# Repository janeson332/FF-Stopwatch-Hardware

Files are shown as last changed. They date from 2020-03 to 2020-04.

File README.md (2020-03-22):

# FF-Stopwatch-Hardware
This Repo contains the hardware layout of the FF-Stopwatch project. The project
has been designed in EAGLE

## Folderstructure
| ..  
|-- doc      &nbsp;&nbsp;&nbsp;&nbsp;&nbsp;&nbsp;&nbsp;&nbsp;&nbsp; < contains docoumentation  
|-- Lib      &nbsp;&nbsp;&nbsp;&nbsp;&nbsp;&nbsp;&nbsp;&nbsp;&nbsp;&nbsp; < Eagle library files  
|-- schematic   < schematic and layout (eagle)  
|-- images   &nbsp;&nbsp;&nbsp;&nbsp; < images of the layout

### bare board
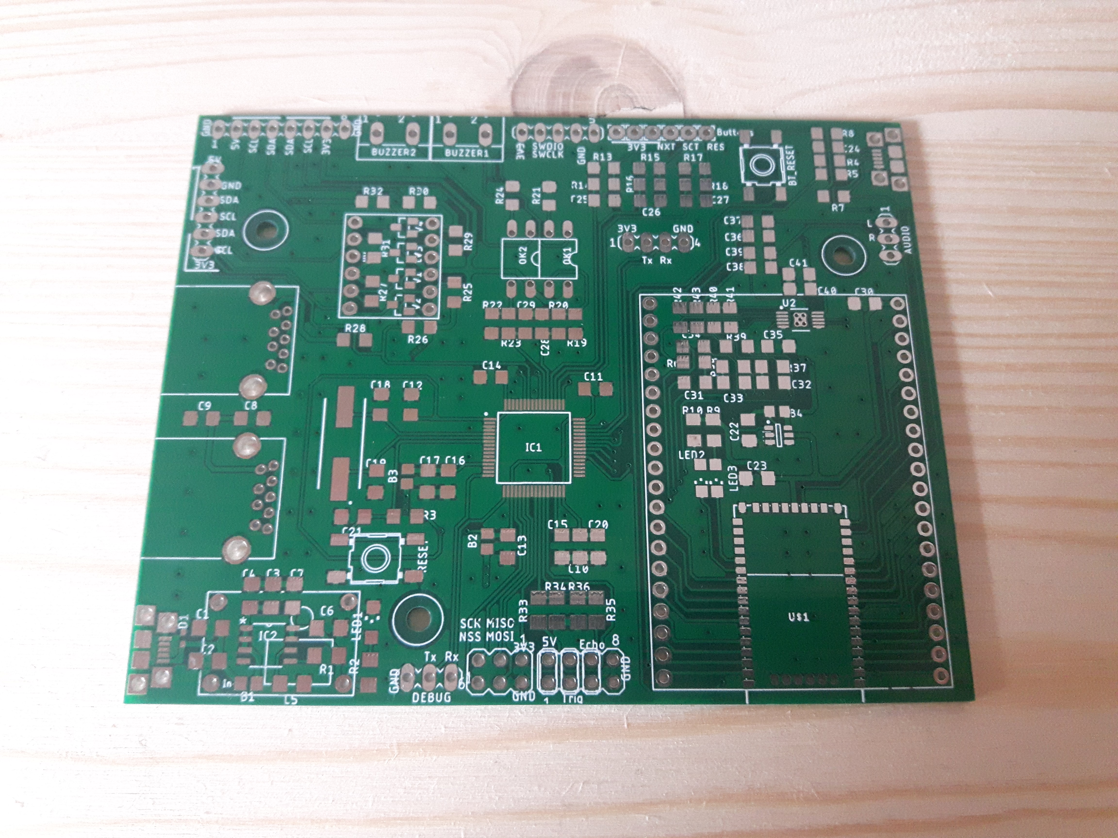
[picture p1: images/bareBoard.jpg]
bare board


### assembled board
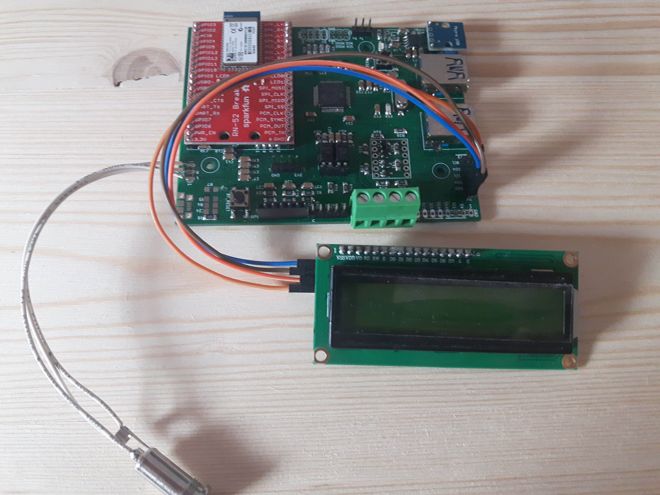
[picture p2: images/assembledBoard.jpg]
bare board


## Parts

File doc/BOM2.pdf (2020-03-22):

Part | Value | Device | Package | Description
AUDIO | | MA03-1 | MA03-1 | PIN HEADER
B1 | B-EU_B0805 L0805 | EMI Filter
B2 | B-EU_B0805 L0805 | EMI Filter
B3 | B-EU_B0805 L0805 | EMI Filter
B4 | B-EU_B0805 L0805 | EMI Filter
BTN_NXT/1 WIREPAD2,15/1,0 WIREPAD2,15/1,0 2,15/1,0 | Wire PAD connect wire on PCB
BTN_RES/1 | WIREPAD2,15/1,0 WIREPAD2,15/1,0 2,15/1,0 | Wire PAD connect wire on PCB
BTN_SCT/1 | WIREPAD2,15/1,0 WIREPAD2,15/1,0 2,15/1,0 | Wire PAD connect wire on PCB
BT_RESET | FactoryReset TASTER_SMD TASTER_SMD_LSG-LSH1301XX 6.0 X 6.0mm TACT Switch (SMD) - Schurter Typ LSG/LSH 1301.xx
BUZZER1 | | W237-102 | W237-102 | WAGO SCREW CLAMP
BUZZER2 | | W237-102 | W237-102 | WAGO SCREW CLAMP
C1 | 10u | C-EUC1206 | C1206 | CAPACITOR, European symbol
C2 | 100n | C-EUC1206 | C1206 | CAPACITOR, European symbol
C3 | 100n | C-EUC1206 | C1206 | CAPACITOR, European symbol
C4 | 10u | C-EUC1206 | C1206 | CAPACITOR, European symbol
C5 | 100n | C-EUC1206 | C1206 | CAPACITOR, European symbol
C6 | 100n | C-EUC1206 | C1206 | CAPACITOR, European symbol
C7 | 10u | C-EUC1206 | C1206 | CAPACITOR, European symbol
C8 | 100n | C-EUC1206 | C1206 | CAPACITOR, European symbol
C9 | 100n | C-EUC1206 | C1206 | CAPACITOR, European symbol
C10 | 10u | C-EUC1206 | C1206 | CAPACITOR, European symbol
C11 | 100n | C-EUC1206 | C1206 | CAPACITOR, European symbol
C12 | 100n | C-EUC1206 | C1206 | CAPACITOR, European symbol
C13 | 100n | C-EUC1206 | C1206 | CAPACITOR, European symbol
C14 | 100n | C-EUC1206 | C1206 | CAPACITOR, European symbol
C15 | 4u7 | C-EUC1206 | C1206 | CAPACITOR, European symbol
C16 | 1u | C-EUC1206 | C1206 | CAPACITOR, European symbol
C17 | 100n | C-EUC1206 | C1206 | CAPACITOR, European symbol
C18 | 15p | C-EUC1206 | C1206 | CAPACITOR, European symbol
C19 | 15p | C-EUC1206 | C1206 | CAPACITOR, European symbol
C20 | 100n | C-EUC1206 | C1206 | CAPACITOR, European symbol
C21 | 100n | C-EUC1206 | C1206 | CAPACITOR, European symbol

C22 | 100n | C-EUC1206 | C1206 | CAPACITOR, European symbol
C23 | 100n | C-EUC1206 | C1206 | CAPACITOR, European symbol
C24 | 100n | C-EUC1206 | C1206 | CAPACITOR, European symbol
C25 | 100n | C-EUC1206 | C1206 | CAPACITOR, European symbol
C26 | 100n | C-EUC1206 | C1206 | CAPACITOR, European symbol
C27 | 100n | C-EUC1206 | C1206 | CAPACITOR, European symbol
C28 | 100n | C-EUC1206 | C1206 | CAPACITOR, European symbol
C29 | 100n | C-EUC1206 | C1206 | CAPACITOR, European symbol
C30 | 100n | C-EUC1206 | C1206 | CAPACITOR, European symbol
C31 | 1u | C-EUC1206 | C1206 | CAPACITOR, European symbol
C32 | 1u | C-EUC1206 | C1206 | CAPACITOR, European symbol
C33 | 1u | C-EUC1206 | C1206 | CAPACITOR, European symbol
C34 | 1u | C-EUC1206 | C1206 | CAPACITOR, European symbol
C35 | 1u | C-EUC1206 | C1206 | CAPACITOR, European symbol
C36 | 100n | C-EUC1206 | C1206 | CAPACITOR, European symbol
C37 | 100n | C-EUC1206 | C1206 | CAPACITOR, European symbol
C38 | 100n | C-EUC1206 | C1206 | CAPACITOR, European symbol
C39 | 100n | C-EUC1206 | C1206 | CAPACITOR, European symbol
C40 | 10u | C-EUC1206 | C1206 | CAPACITOR, European symbol
C41 | 100n | C-EUC1206 | C1206 | CAPACITOR, European symbol
D1 | PESD5V0S1UBDIODE-SOD523SOD523 | DIODE
DEBUG | | MA03-1 | MA03-1 | PIN HEADER
H1 | MOUNT-HOLE2.8 MOUNT-HOLE2.8 | 2,8 MOUNTING HOLE with drill center marker
H2 | MOUNT-HOLE2.8 MOUNT-HOLE2.8 | 2,8 MOUNTING HOLE with drill center marker
H3 | MOUNT-HOLE2.8 MOUNT-HOLE2.8 | 2,8 MOUNTING HOLE with drill center marker
IC1 | STM32F401RET6STM32F401RET6QFP50P1200X1200X160-64N ARM Cortex-M4 32b MCU+FPU
IC2 | MCP1725-3302E/SN MCP1725-3302E/SN SOIC127P600X175-8N Low Quiescent Current LDO Regulator
J1 | USB-A3-0 | USB3_TYPE_A WR-COM USB 3.0 HORIZONTAL TYPE A=>Code : Con_I-O_COM_USB-3.0_A_629121030100
J2 | USB-A3-0 | USB3_TYPE_A WR-COM USB 3.0 HORIZONTAL TYPE A=>Code : Con_I-O_COM_USB-3.0_A_629121030100
LED1 | RED | LEDCHIPLED_1206 CHIPLED_1206LED
LED2 | GREEN | LEDCHIPLED_1206 CHIPLED_1206LED
LED3 | RED | LEDCHIPLED_1206 CHIPLED_1206LED
NXT | WIREPAD2,15/1,0 WIREPAD2,15/1,0 2,15/1,0 | Wire PAD connect wire on PCB

OK1 | PC817 | PC817 | DIL04 | SHARP OPTO COUPLER
OK2 | PC817 | PC817 | DIL04 | SHARP OPTO COUPLER
Q1 | 8MHz | FOXSDLF_080-20FOXSDLF/080-20Crystal SMD 8.000MHz HC49S-SMD Crystal 8MHz, 30ppm, 2-Pin SMD, 11.7 x 5 x 4.5mm
R1 | 100k | R-EU_R1206 R1206 | RESISTOR, European symbol
R2 | 330R | R-EU_R1206 R1206 | RESISTOR, European symbol
R3 | 100k | R-EU_R1206 R1206 | RESISTOR, European symbol
R4 | 22k | R-EU_R1206 R1206 | RESISTOR, European symbol
R5 | 47k | R-EU_R1206 R1206 | RESISTOR, European symbol
R6 | 22k | R-EU_R1206 R1206 | RESISTOR, European symbol
R7 | 1k5 | R-EU_R1206 R1206 | RESISTOR, European symbol
R8 | 1k5 | R-EU_R1206 R1206 | RESISTOR, European symbol
R9 | 330 R-EU_R1206 R1206 | RESISTOR, European symbol
R10 | 330 R-EU_R1206 R1206 | RESISTOR, European symbol
R13 | 10k | R-EU_R1206 R1206 | RESISTOR, European symbol
R14 | 10k | R-EU_R1206 R1206 | RESISTOR, European symbol
R15 | 10k | R-EU_R1206 R1206 | RESISTOR, European symbol
R16 | 10k | R-EU_R1206 R1206 | RESISTOR, European symbol
R17 | 10k | R-EU_R1206 R1206 | RESISTOR, European symbol
R18 | 10k | R-EU_R1206 R1206 | RESISTOR, European symbol
R19 | 10k | R-EU_R1206 R1206 | RESISTOR, European symbol
R20 | 10k | R-EU_R1206 R1206 | RESISTOR, European symbol
R21 | 330R | R-EU_R1206 R1206 | RESISTOR, European symbol
R22 | 10k | R-EU_R1206 R1206 | RESISTOR, European symbol
R23 | 10k | R-EU_R1206 R1206 | RESISTOR, European symbol
R24 | 330R | R-EU_R1206 R1206 | RESISTOR, European symbol
R25 | 3k3 | R-EU_R1206 R1206 | RESISTOR, European symbol
R26 | 3k3 | R-EU_R1206 R1206 | RESISTOR, European symbol
R27 | 4k7 | R-EU_R1206 R1206 | RESISTOR, European symbol
R28 | 4k7 | R-EU_R1206 R1206 | RESISTOR, European symbol
R29 | 3k3 | R-EU_R1206 R1206 | RESISTOR, European symbol
R30 | 3k3 | R-EU_R1206 R1206 | RESISTOR, European symbol
R31 | 4k7 | R-EU_R1206 R1206 | RESISTOR, European symbol
R32 | 4k7 | R-EU_R1206 R1206 | RESISTOR, European symbol

R33 | 22k | R-EU_R1206 R1206 | RESISTOR, European symbol
R34 | 47k | R-EU_R1206 R1206 | RESISTOR, European symbol
R35 | 22k | R-EU_R1206 R1206 | RESISTOR, European symbol
R36 | 47k | R-EU_R1206 R1206 | RESISTOR, European symbol
R37 | 22k | R-EU_R1206 R1206 | RESISTOR, European symbol
R38 | 22k | R-EU_R1206 R1206 | RESISTOR, European symbol
R39 | 22k | R-EU_R1206 R1206 | RESISTOR, European symbol
R40 | 47k | R-EU_R1206 R1206 | RESISTOR, European symbol
R41 | 47k | R-EU_R1206 R1206 | RESISTOR, European symbol
R42 | 47k | R-EU_R1206 R1206 | RESISTOR, European symbol
R43 | 47k | R-EU_R1206 R1206 | RESISTOR, European symbol
RES | WIREPAD2,15/1,0 WIREPAD2,15/1,0 2,15/1,0 | Wire PAD connect wire on PCB
RESET | Reset | TASTER_SMD TASTER_SMD_LSG-LSH1301XX 6.0 X 6.0mm TACT Switch (SMD) - Schurter Typ LSG/LSH 1301.xx
SCT | WIREPAD2,15/1,0 WIREPAD2,15/1,0 2,15/1,0 | Wire PAD connect wire on PCB
SV1 | | MA05-1 | MA05-1 | PIN HEADER
SV2 | | MA04-2 | MA04-2 | PIN HEADER
SV3 | | MA06-1 | MA06-1 | PIN HEADER
SV5 | | MA04-1 | MA04-1 | PIN HEADER
SV6 | | MA03-2 | MA03-2 | PIN HEADER
SV7 | | MA08-1 | MA08-1 | PIN HEADER
U$1 | BLUETOOTH-RN-52 BLUETOOTH-RN-52 RN-52 | Roving Networks RN-52 Bluetooth Audio Module
U$2 | SPARKFUN-RN52SPARKFUN-RN52SPARKFUN-RN52
U$3 | I2C-LEVELCONVERTER-PCB I2C-LEVELCONVERTER-PCB I2C-LEVELCONVERTER-PCB
U$4 | RC-STEP-DOWNRC-STEP-DOWNRC-STEP-DOWN
U1 | ANALOG_DEVICES_ADG819BRTZ-500RL7ANALOG_DEVICES_ADG819BRTZ-500RL7_0_1 ANALOG_DEVICES_ADG819BRTZ-500RL7ANALOG_DEVICES_ADG819BRTZ-500RL7_0_1 ANALOG_DEVICES_ADG819BRTZ-500RL7_1 ADI-ADG819-RJ-6
U2 | TEXAS_INSTRUMENTS_TPA6112A2DGQRTEXAS_INSTRUMENTS_TPA6112A2DGQR_0_1 TEXAS_INSTRUMENTS_TPA6112A2DGQRTEXAS_INSTRUMENTS_TPA6112A2DGQR_0_1 TEXAS_INSTRUMENTS_TPA6112A2DGQR_1 TI-TPA6112A2DGQ10-1675X1445TP
USB1 | MICRO-USB MICRO-USB ZX62B5PA
USB2 | MICRO-USB MICRO-USB ZX62B5PA
V1 | FDN337N | FDN337N | SOT23 | N-CHANNEL MOS FET
V2 | FDN337N | FDN337N | SOT23 | N-CHANNEL MOS FET
V3 | FDN337N | FDN337N | SOT23 | N-CHANNEL MOS FET
V4 | FDN337N | FDN337N | SOT23 | N-CHANNEL MOS FET

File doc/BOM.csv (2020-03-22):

Qty | Value | Device | Package | Parts | Description
4 |  | B-EU_B0805 | L0805 | B1, B2, B3, B4 | EMI Filter
2 |  | MA03-1 | MA03-1 | AUDIO, DEBUG | PIN HEADER
1 |  | MA03-2 | MA03-2 | SV6 | PIN HEADER
1 |  | MA04-1 | MA04-1 | SV5 | PIN HEADER
1 |  | MA04-2 | MA04-2 | SV2 | PIN HEADER
1 |  | MA05-1 | MA05-1 | SV1 | PIN HEADER
1 |  | MA06-1 | MA06-1 | SV3 | PIN HEADER
1 |  | MA08-1 | MA08-1 | SV7 | PIN HEADER
2 |  | USB-A3-0 | USB3_TYPE_A | J1, J2 | WR-COM USB 3.0 HORIZONTAL TYPE A=>Code : Con_I-O_COM_USB-3.0_A_629121030100
2 |  | W237-102 | W237-102 | BUZZER1, BUZZER2 | WAGO SCREW CLAMP
2 | 100k | R-EU_R1206 | R1206 | R1, R3 | RESISTOR, European symbol
27 | 100n | C-EUC1206 | C1206 | C2, C3, C5, C6, C8, C9, C11, C12, C13, C14, C17, C20, C21, C22, C23, C24, C25, C26, C27, C28, C29, C30, C36, C37, C38, C39, C41 | CAPACITOR, European symbol
10 | 10k | R-EU_R1206 | R1206 | R13, R14, R15, R16, R17, R18, R19, R20, R22, R23 | RESISTOR, European symbol
5 | 10u | C-EUC1206 | C1206 | C1, C4, C7, C10, C40 | CAPACITOR, European symbol
2 | 15p | C-EUC1206 | C1206 | C18, C19 | CAPACITOR, European symbol
2 | 1k5 | R-EU_R1206 | R1206 | R7, R8 | RESISTOR, European symbol
6 | 1u | C-EUC1206 | C1206 | C16, C31, C32, C33, C34, C35 | CAPACITOR, European symbol
7 | 22k | R-EU_R1206 | R1206 | R4, R6, R33, R35, R37, R38, R39 | RESISTOR, European symbol
2 | 330 | R-EU_R1206 | R1206 | R9, R10 | RESISTOR, European symbol
3 | 330R | R-EU_R1206 | R1206 | R2, R21, R24 | RESISTOR, European symbol
4 | 3k3 | R-EU_R1206 | R1206 | R25, R26, R29, R30 | RESISTOR, European symbol
7 | 47k | R-EU_R1206 | R1206 | R5, R34, R36, R40, R41, R42, R43 | RESISTOR, European symbol
4 | 4k7 | R-EU_R1206 | R1206 | R27, R28, R31, R32 | RESISTOR, European symbol
1 | 4u7 | C-EUC1206 | C1206 | C15 | CAPACITOR, European symbol
1 | 8MHz | FOXSDLF_080-20 | FOXSDLF/080-20 | Q1 | Crystal SMD 8.000MHz HC49S-SMD Crystal 8MHz, 30ppm, 2-Pin SMD, 11.7 x 5 x 4.5mm
1 | ANALOG_DEVICES_ADG819BRTZ-500RL7ANALOG_DEVICES_ADG819BRTZ-500RL7_0_1 | ANALOG_DEVICES_ADG819BRTZ-500RL7ANALOG_DEVICES_ADG819BRTZ-500RL7_0_1 | ANALOG_DEVICES_ADG819BRTZ-500RL7_1 | U1 | ADI-ADG819-RJ-6
1 | BLUETOOTH-RN-52 | BLUETOOTH-RN-52 | RN-52 | U$1 | Roving Networks RN-52 Bluetooth Audio Module
4 | FDN337N | FDN337N | SOT23 | V1, V2, V3, V4 | N-CHANNEL MOS FET
1 | FactoryReset | TASTER_SMD | TASTER_SMD_LSG-LSH1301XX | BT_RESET | 6.0 X 6.0mm TACT Switch (SMD) - Schurter Typ LSG/LSH 1301.xx
1 | GREEN | LEDCHIPLED_1206 | CHIPLED_1206 | LED2 | LED
1 | I2C-LEVELCONVERTER-PCB | I2C-LEVELCONVERTER-PCB | I2C-LEVELCONVERTER-PCB | U$3
1 | MCP1725-3302E/SN | MCP1725-3302E/SN | SOIC127P600X175-8N | IC2 | Low Quiescent Current LDO Regulator
2 | MICRO-USB | MICRO-USB | ZX62B5PA | USB1, USB2
3 | MOUNT-HOLE2.8 | MOUNT-HOLE2.8 | 2,8 | H1, H2, H3 | MOUNTING HOLE with drill center marker
2 | PC817 | PC817 | DIL04 | OK1, OK2 | SHARP OPTO COUPLER
1 | PESD5V0S1UB | DIODE-SOD523 | SOD523 | D1 | DIODE
1 | RC-STEP-DOWN | RC-STEP-DOWN | RC-STEP-DOWN | U$4
2 | RED | LEDCHIPLED_1206 | CHIPLED_1206 | LED1, LED3 | LED
1 | Reset | TASTER_SMD | TASTER_SMD_LSG-LSH1301XX | RESET | 6.0 X 6.0mm TACT Switch (SMD) - Schurter Typ LSG/LSH 1301.xx
1 | SPARKFUN-RN52 | SPARKFUN-RN52 | SPARKFUN-RN52 | U$2
1 | STM32F401RET6 | STM32F401RET6 | QFP50P1200X1200X160-64N | IC1 | ARM Cortex-M4 32b MCU+FPU
1 | TEXAS_INSTRUMENTS_TPA6112A2DGQRTEXAS_INSTRUMENTS_TPA6112A2DGQR_0_1 | TEXAS_INSTRUMENTS_TPA6112A2DGQRTEXAS_INSTRUMENTS_TPA6112A2DGQR_0_1 | TEXAS_INSTRUMENTS_TPA6112A2DGQR_1 | U2 | TI-TPA6112A2DGQ10-1675X1445TP
6 | WIREPAD2,15/1,0 | WIREPAD2,15/1,0 | 2,15/1,0 | BTN_NXT/1, BTN_RES/1, BTN_SCT/1, NXT, RES, SCT | Wire PAD connect wire on PCB

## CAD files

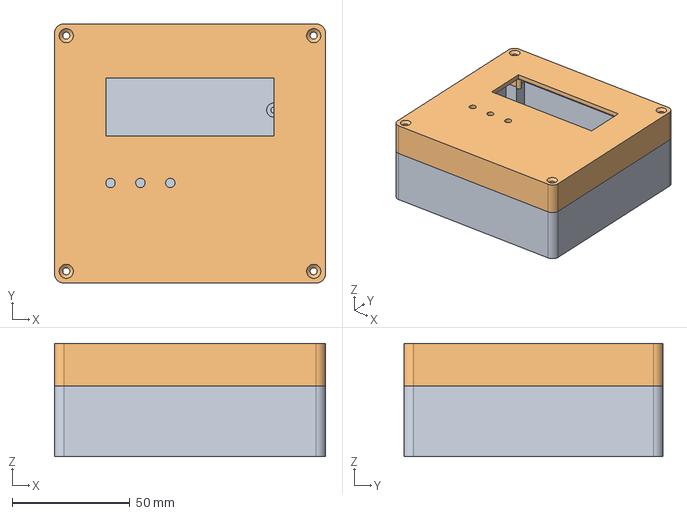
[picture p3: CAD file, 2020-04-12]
Case/Assembled.FCStd
115.0 x 110.0 x 48.0 mm
Case2_001
Cover_001

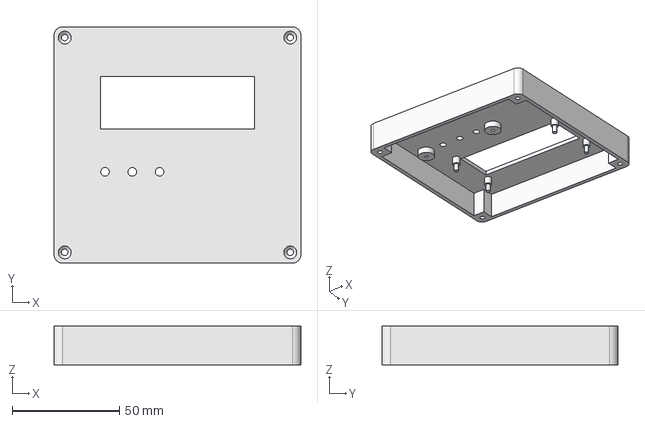
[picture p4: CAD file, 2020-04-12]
Case/Cover.FCStd
115.0 x 110.0 x 18.0 mm

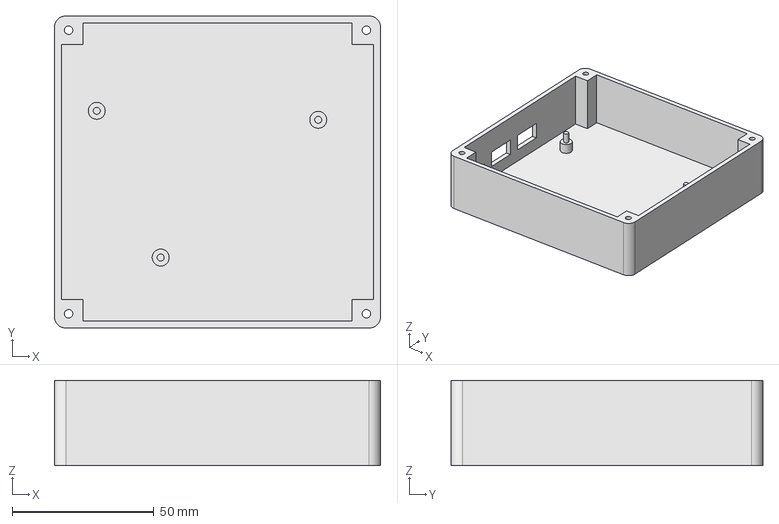
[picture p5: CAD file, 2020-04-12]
Case/Case2.FCStd
115.0 x 110.0 x 30.0 mm

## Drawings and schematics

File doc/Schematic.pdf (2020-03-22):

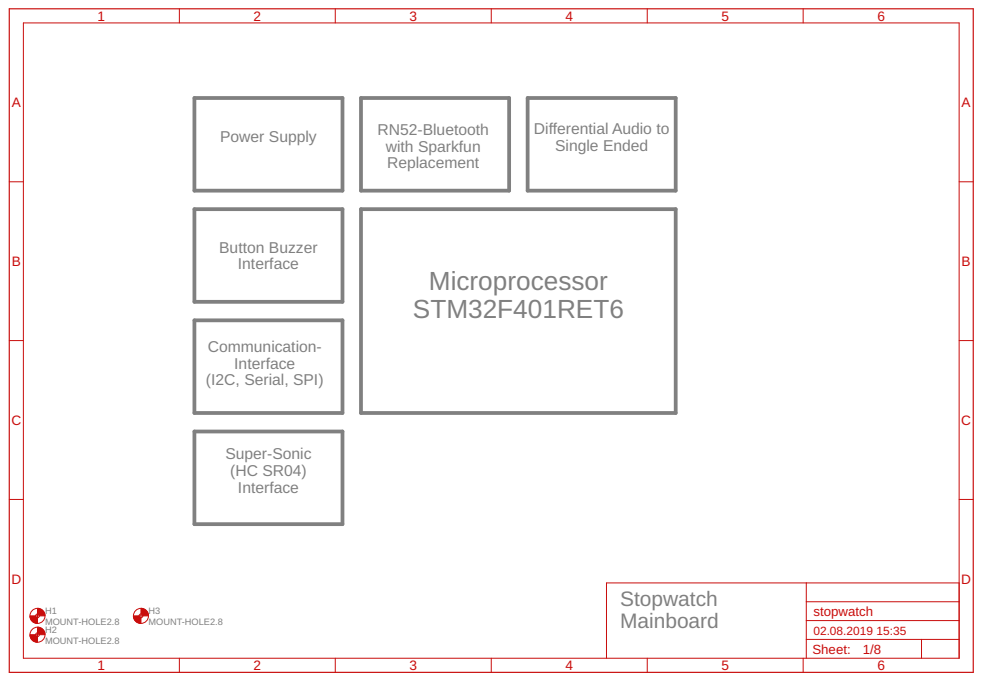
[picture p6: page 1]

Stopwatch

Sheet: 1/8

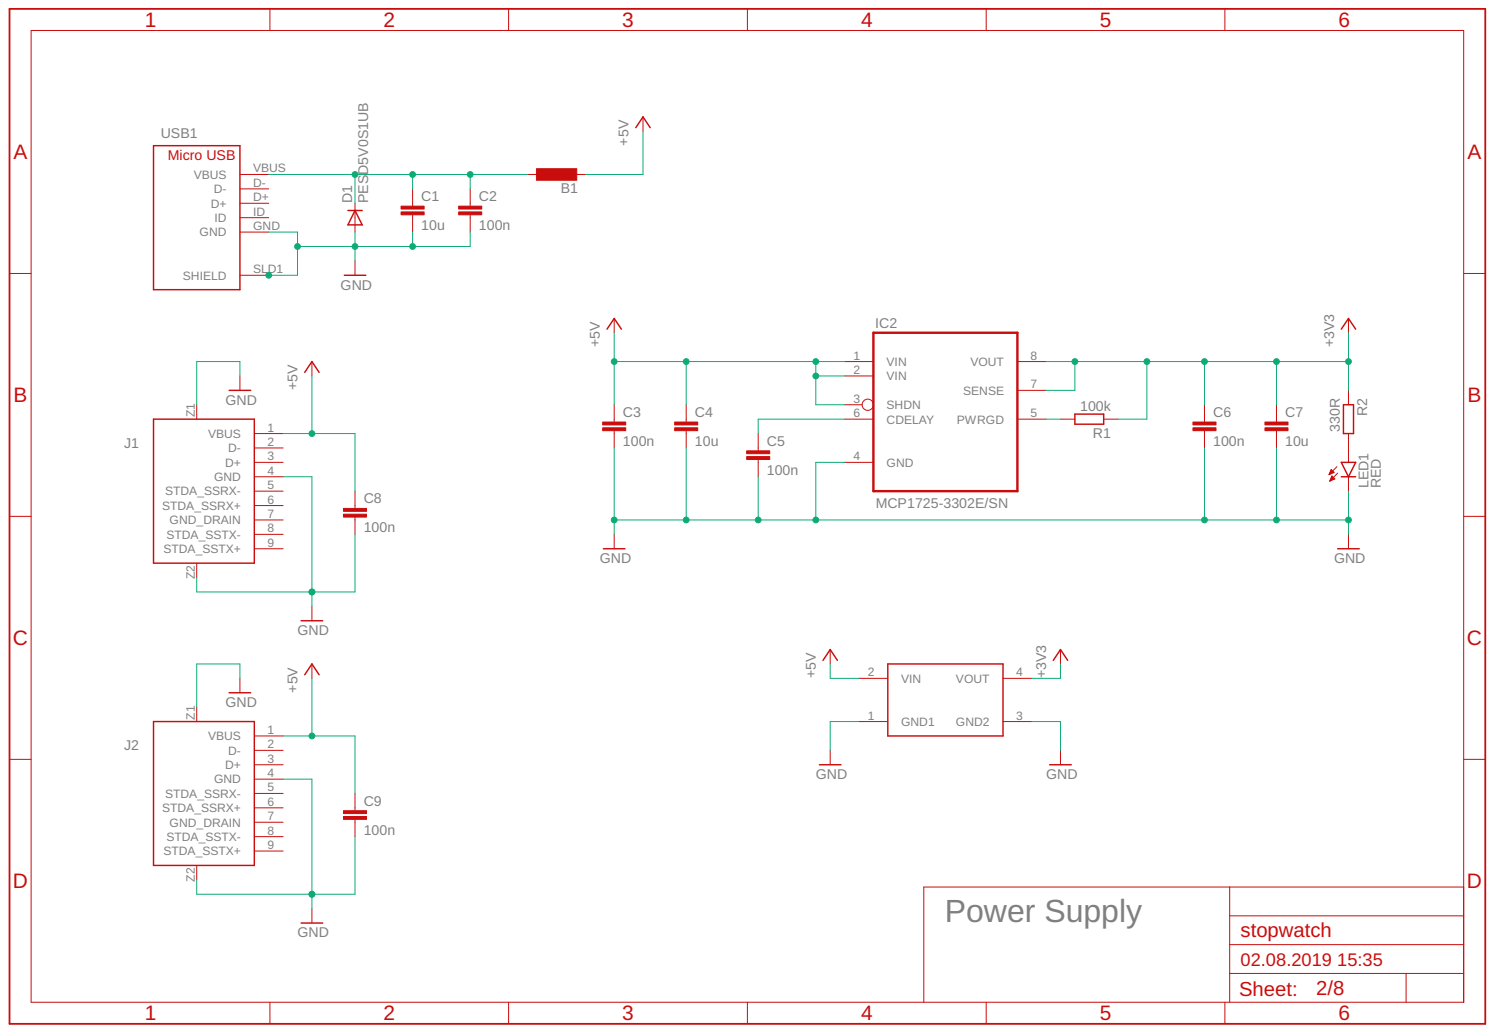
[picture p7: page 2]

PESD5V0S1UB 10u 100n GND +5V +5V GND100n 10u 100n 100k 100n 10u GND 330R RED +3V3 +5V GND GND 100n +5V GND GND 100n +5V +3V3 GND GND MCP1725-3302E/SN Power Supply VBUS VBUS D- D- D+ D+ ID ID GND GND SHIELD SLD1 USB1 D1C1 C2 B1 C3 C4 C5 R1 C6 C7 R2 LED1 J1 VBUS 1 D- 2 D+ 3 GND 4 STDA_SSRX- 5 STDA_SSRX+ 6 GND_DRAIN 7 STDA_SSTX- 8 STDA_SSTX+ 9 Z1 Z2 C8 J2 VBUS 1 D- 2 D+ 3 GND 4 STDA_SSRX- 5 STDA_SSRX+ 6 GND_DRAIN 7 STDA_SSTX- 8 STDA_SSTX+ 9 Z1 Z2 C9 VIN 2 GND1 1 VOUT 4 GND2 3 CDELAY 6 GND 4 PWRGD 5 SENSE 7 SHDN 3 VIN 1 VIN 2 VOUT 8 IC2 stopwatch 02.08.2019 15:35 Sheet: 2/8 ABCD 1 2 3 4 5 6 ABCD 1 2 3 4 5 6 Micro USB

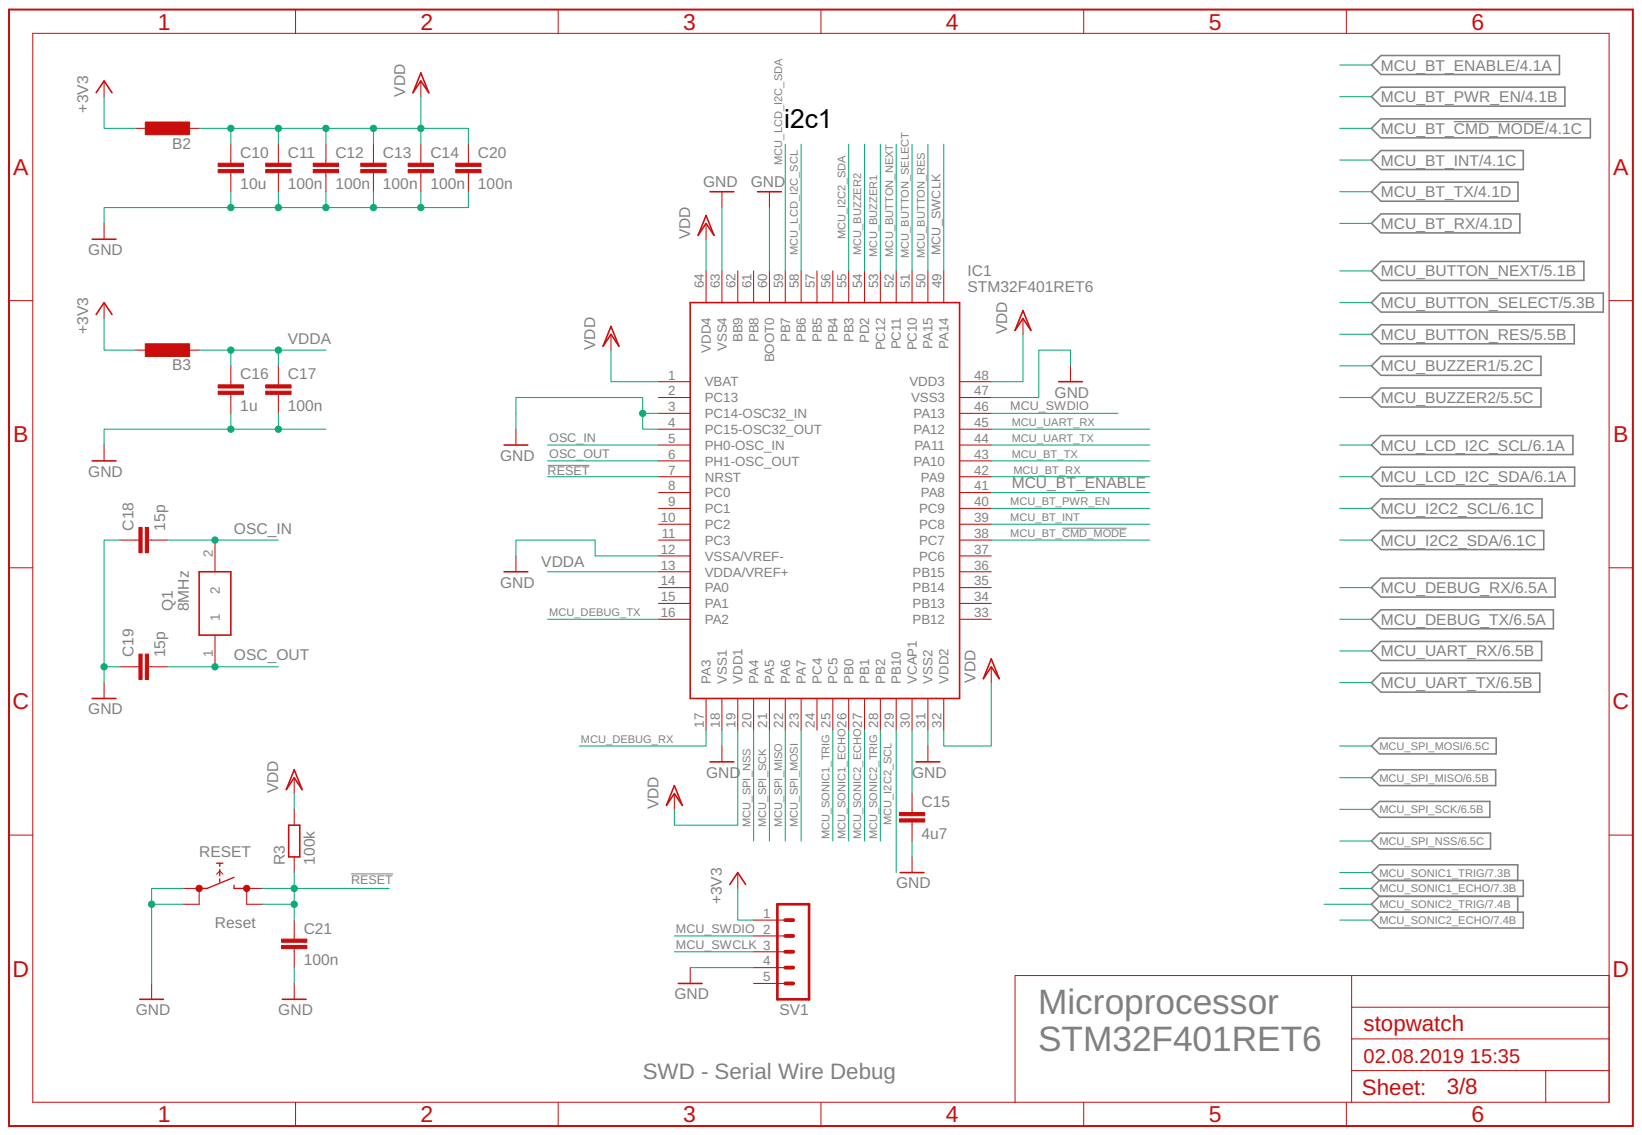
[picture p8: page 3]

Microprocessor STM32F401RET6

SWD - Serial Wire Debug

Sheet: 3/8

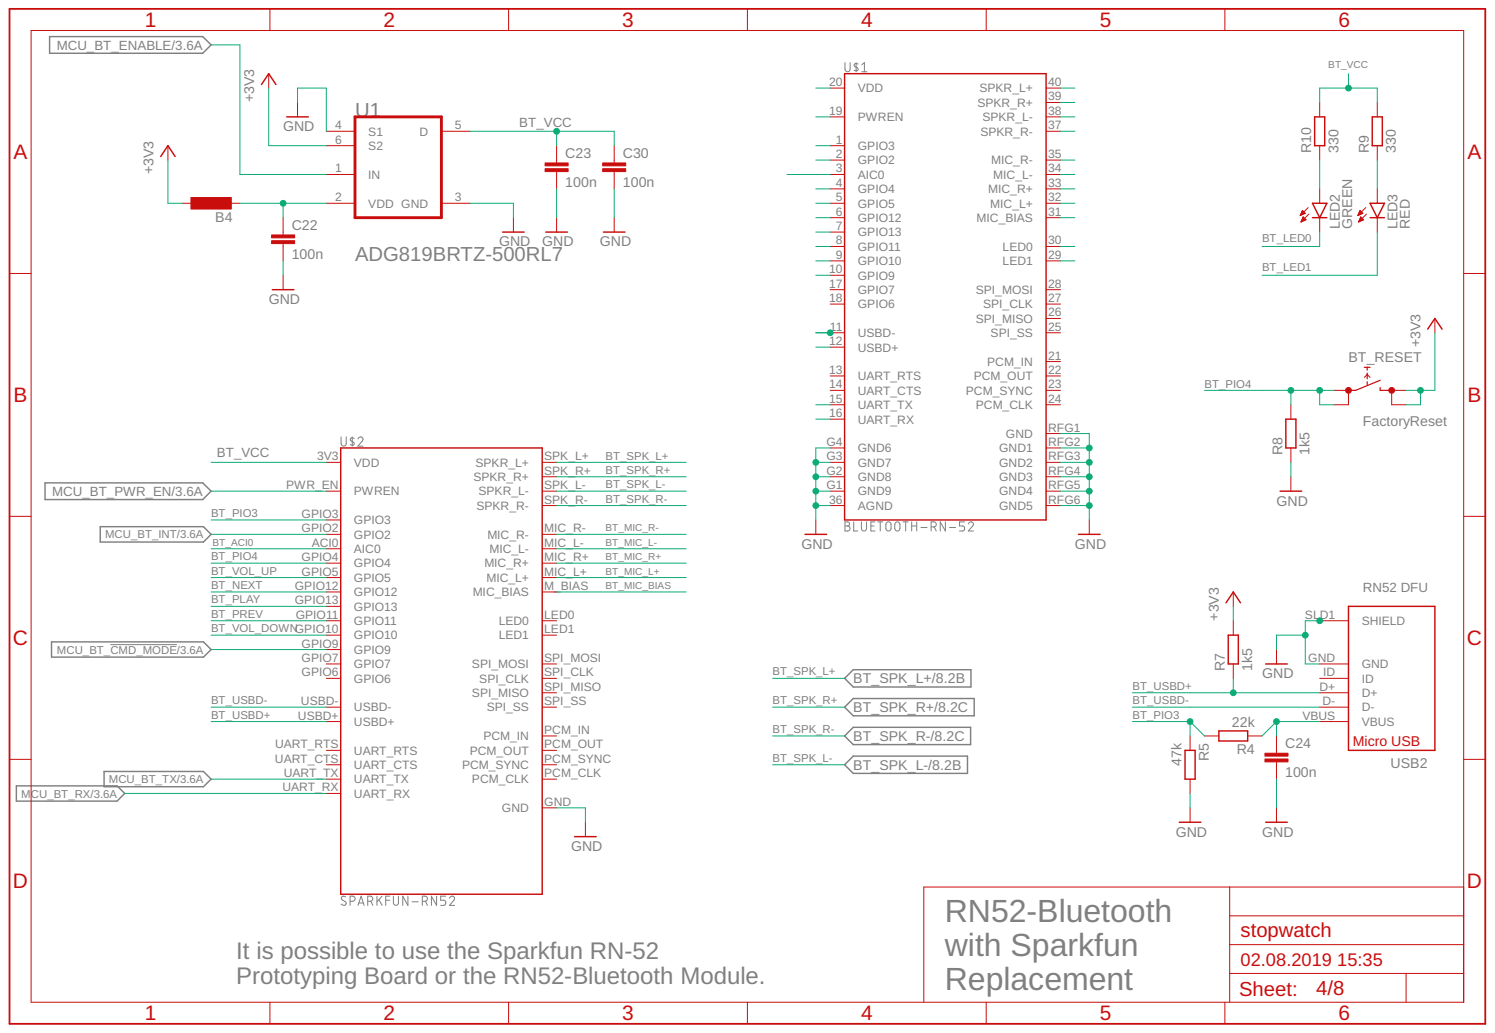
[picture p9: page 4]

RN52-Bluetooth with Sparkfun Replacement

It is possible to use the Sparkfun RN-52
Prototyping Board or the RN52-Bluetooth Module.

Sheet: 4/8

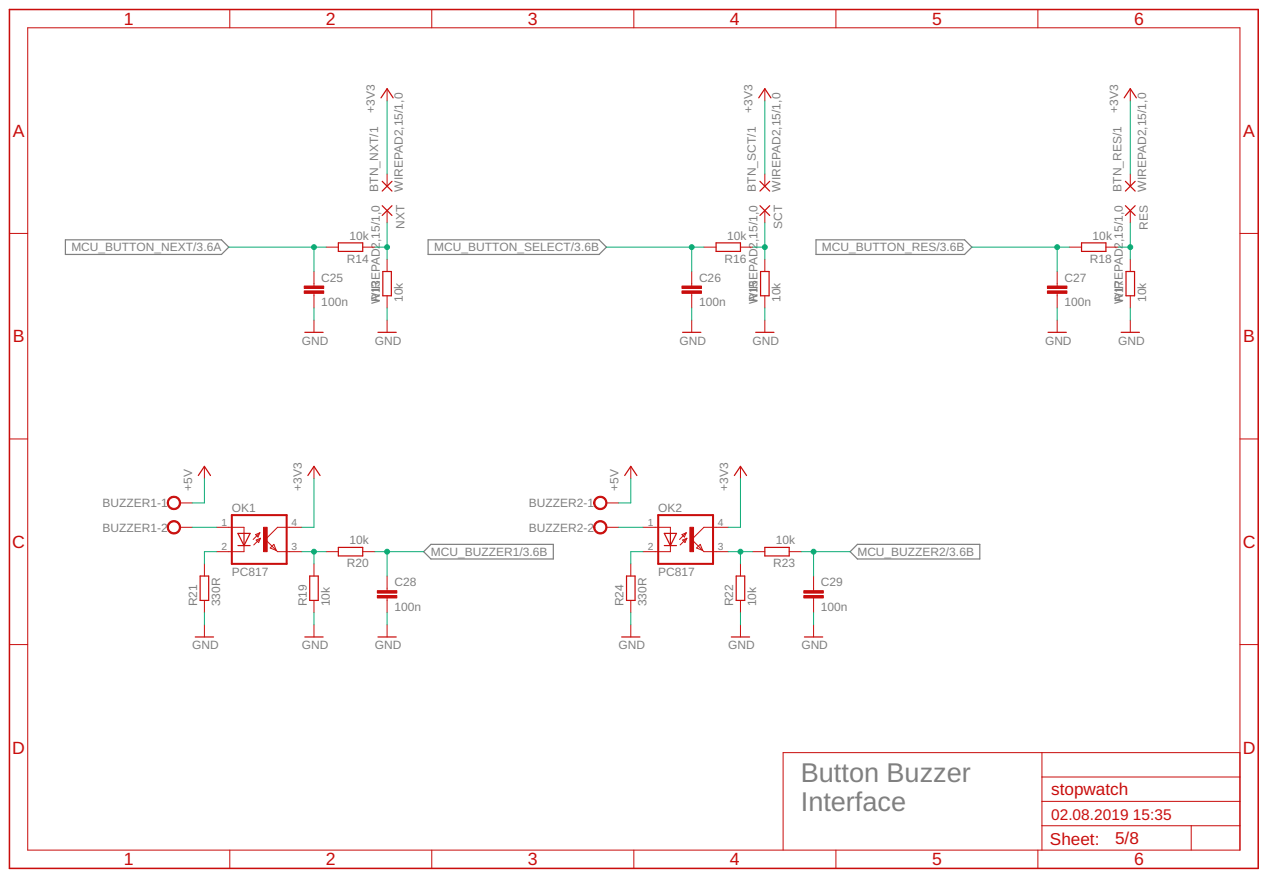
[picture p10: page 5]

Button Buzzer Interface

Sheet: 5/8

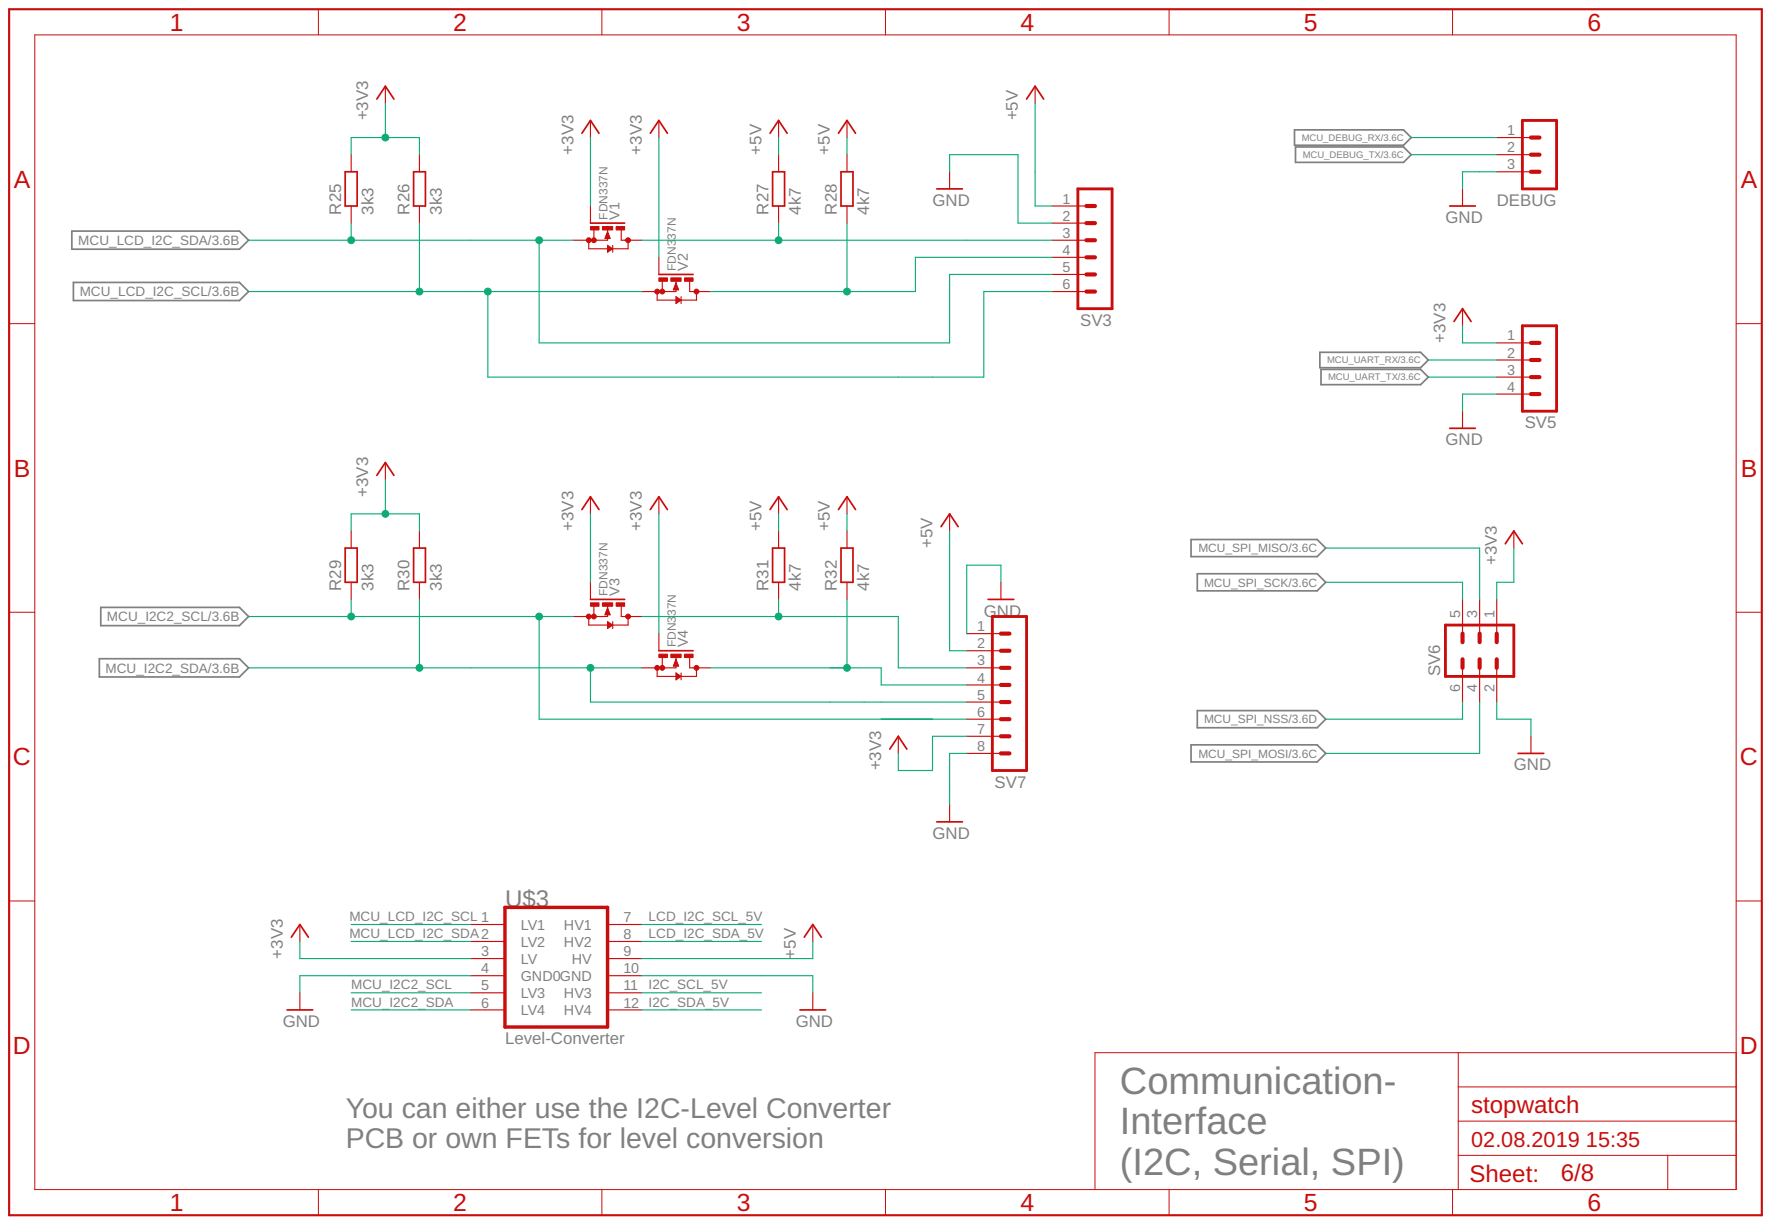
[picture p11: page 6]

Communication-Interface (I2C, Serial, SPI)

You can either use the I2C-Level Converter
PCB or own FETs for level conversion

Sheet: 6/8

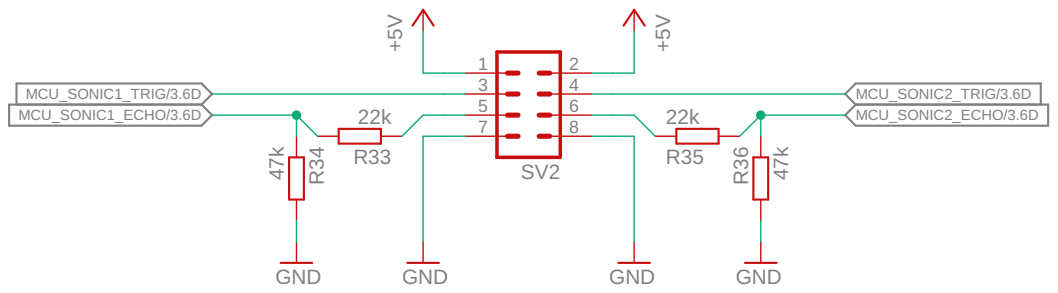
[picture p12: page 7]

Super-Sonic (HC SR04) Interface

Sheet: 7/8

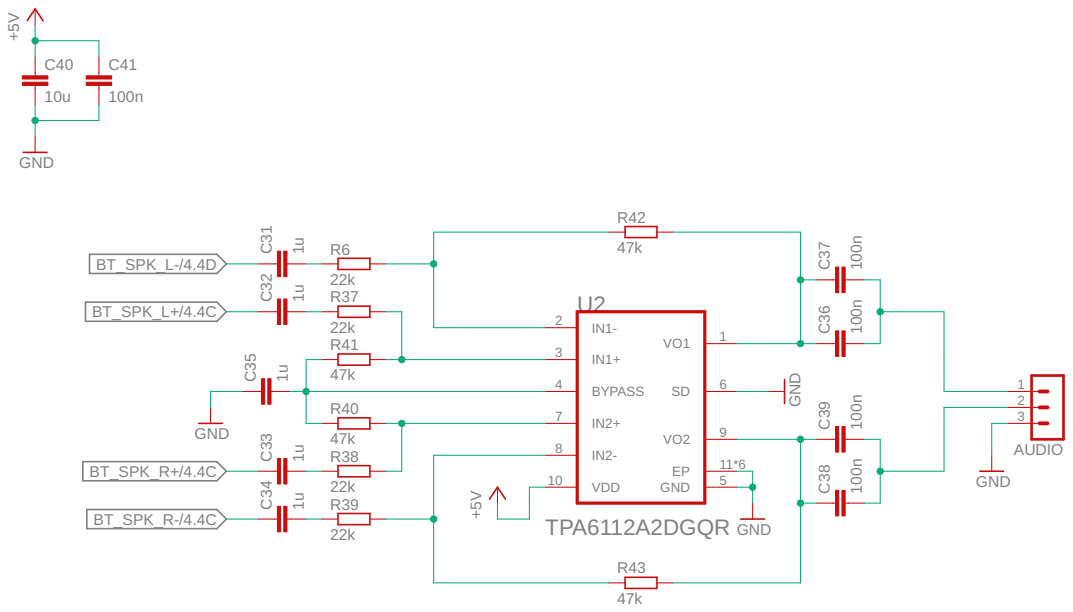
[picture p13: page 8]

Differential Audio to Single Ended

Sheet: 8/8

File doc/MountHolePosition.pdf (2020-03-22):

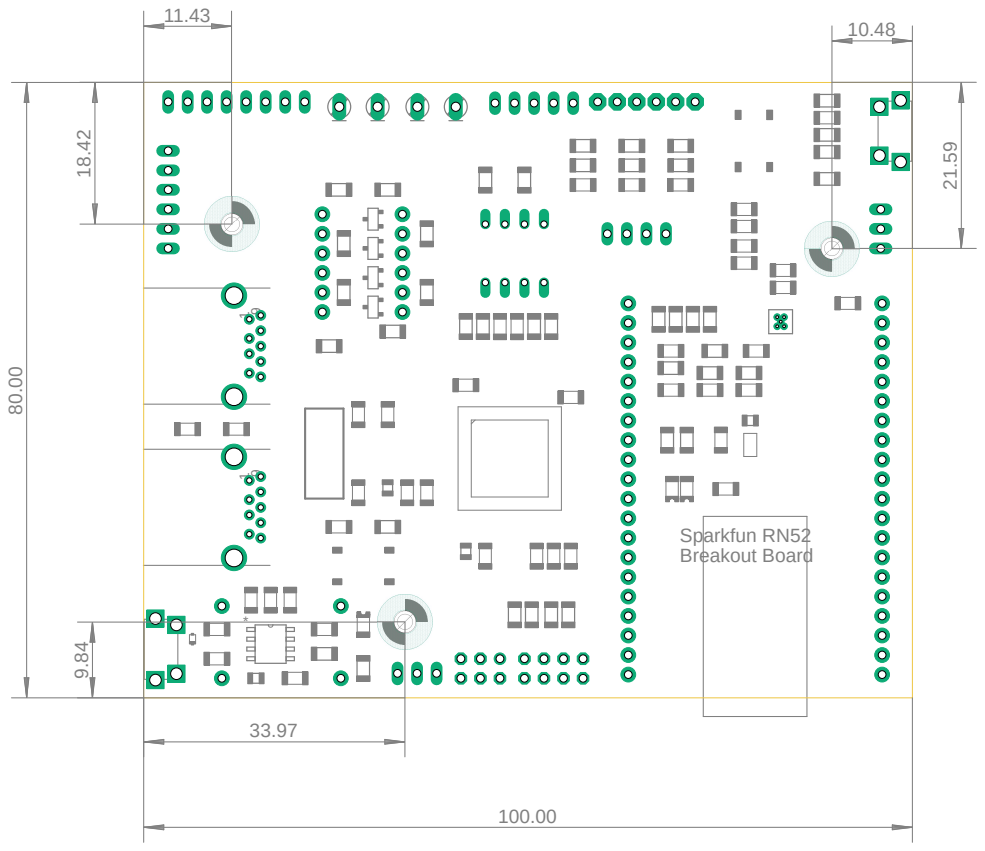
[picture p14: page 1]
Sparkfun RN52 Breakout Board

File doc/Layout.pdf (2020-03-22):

# R20 R²¹

# R23 R²⁴ R²⁵

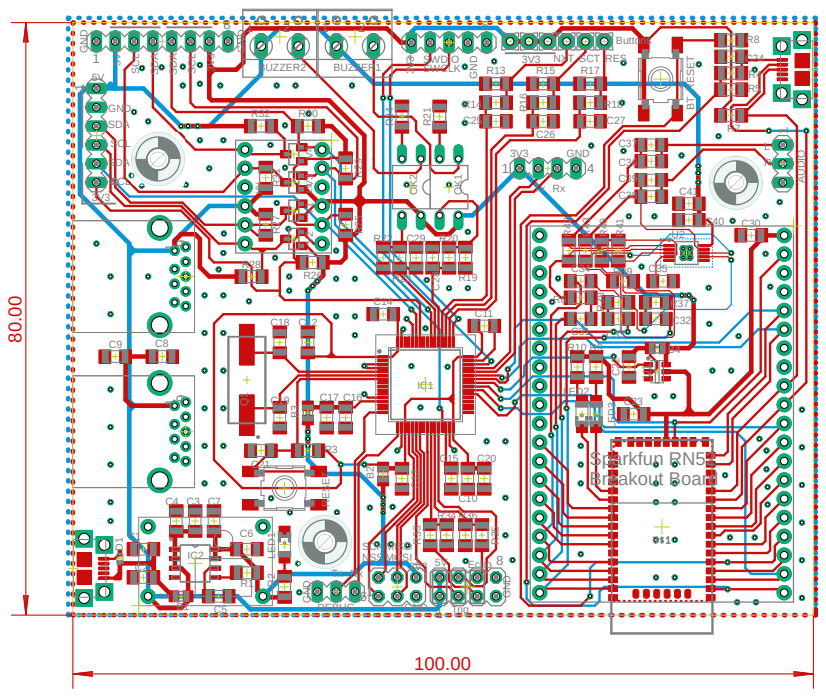
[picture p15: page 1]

DEBUG V¹ V² V³ V⁴

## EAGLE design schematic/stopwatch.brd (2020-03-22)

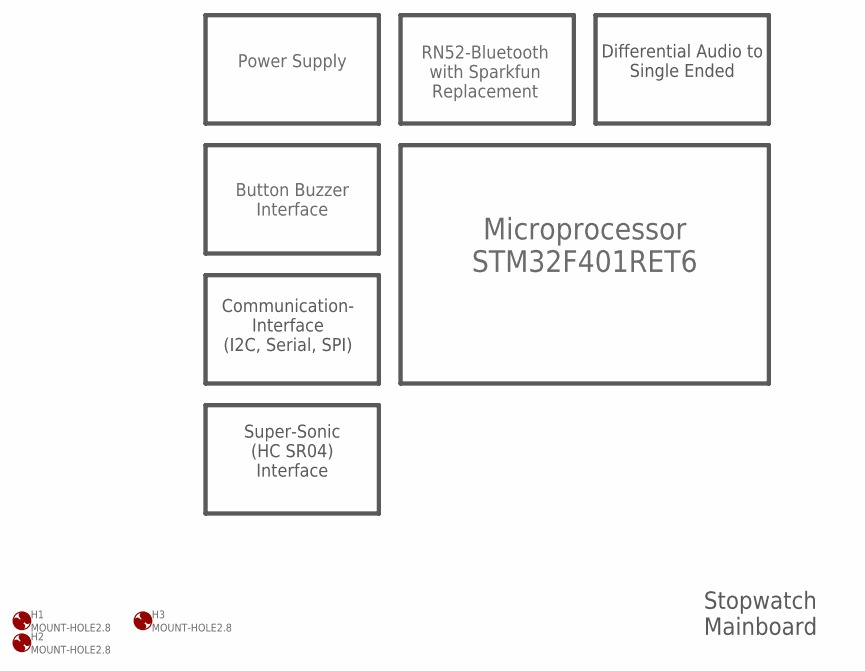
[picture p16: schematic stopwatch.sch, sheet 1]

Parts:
H1, H2, H3: MOUNT-HOLE2.8; 2,8

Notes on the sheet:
Microprocessor STM32F401RET6
Power Supply
RN52-Bluetooth with Sparkfun Replacement
Button Buzzer Interface
Communication- Interface (I2C, Serial, SPI)
Super-Sonic (HC SR04) Interface
Differential Audio to Single Ended
Stopwatch Mainboard

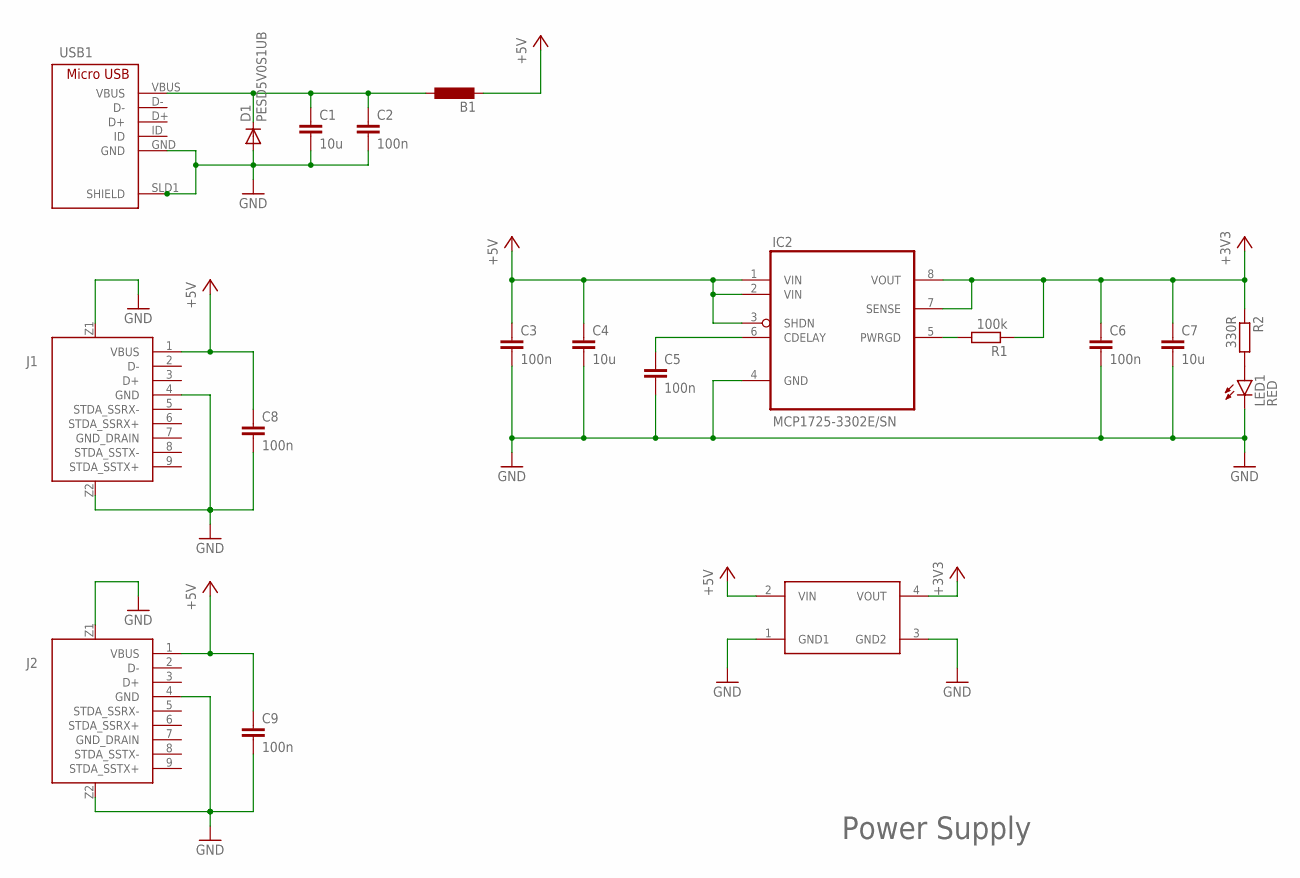
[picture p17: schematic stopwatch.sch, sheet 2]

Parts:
B1: B-EU_B0805; L0805
C1, C4, C7: 10u; C1206
C2, C3, C5, C6, C8, C9: 100n; C1206
D1: PESD5V0S1UB; SOD523
IC2: MCP1725-3302E/SN; SOIC127P600X175-8N
J1, J2: USB-A3-0; USB3_TYPE_A
LED1: RED; CHIPLED_1206
R1: 100k; R1206
R2: 330R; R1206
U$4: RC-STEP-DOWN
USB1: MICRO-USB; ZX62B5PA

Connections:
+3V3: C6.1, C7.1, IC2.7 (SENSE), IC2.8 (VOUT), R1.1, R2.1, U$4.4 (VOUT); also elsewhere on the board
+5V: B1.2, C3.1, C4.1, C8.1, C9.1, IC2.1 (VIN), IC2.2 (VIN), IC2.3 (SHDN), J1.1 (VBUS), J2.1 (VBUS), U$4.2 (VIN); also elsewhere on the board
GND: C1.2, C2.2, C3.2, C4.2, C5.2, C6.2, C7.2, C8.2, C9.2, D1.A, IC2.4 (GND), J1.4 (GND), J1.Z1, J1.Z2, J2.4 (GND), J2.Z1, J2.Z2, LED1.C, U$4.1 (GND1), U$4.3 (GND2), USB1.GND, USB1.SLD1 (SHIELD), USB1.SLD2 (SHIELD2), USB1.SLD3 (SHIELD3), USB1.SLD4 (SHIELD4), USB1.SLD5 (SHIELD5), USB1.SLD6 (SHIELD6); also elsewhere on the board
unnamed: B1.1, C1.1, C2.1, D1.C, USB1.VBUS
unnamed: C5.1, IC2.6 (CDELAY)
unnamed: IC2.5 (PWRGD), R1.2
unnamed: LED1.A, R2.2

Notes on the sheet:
Power Supply

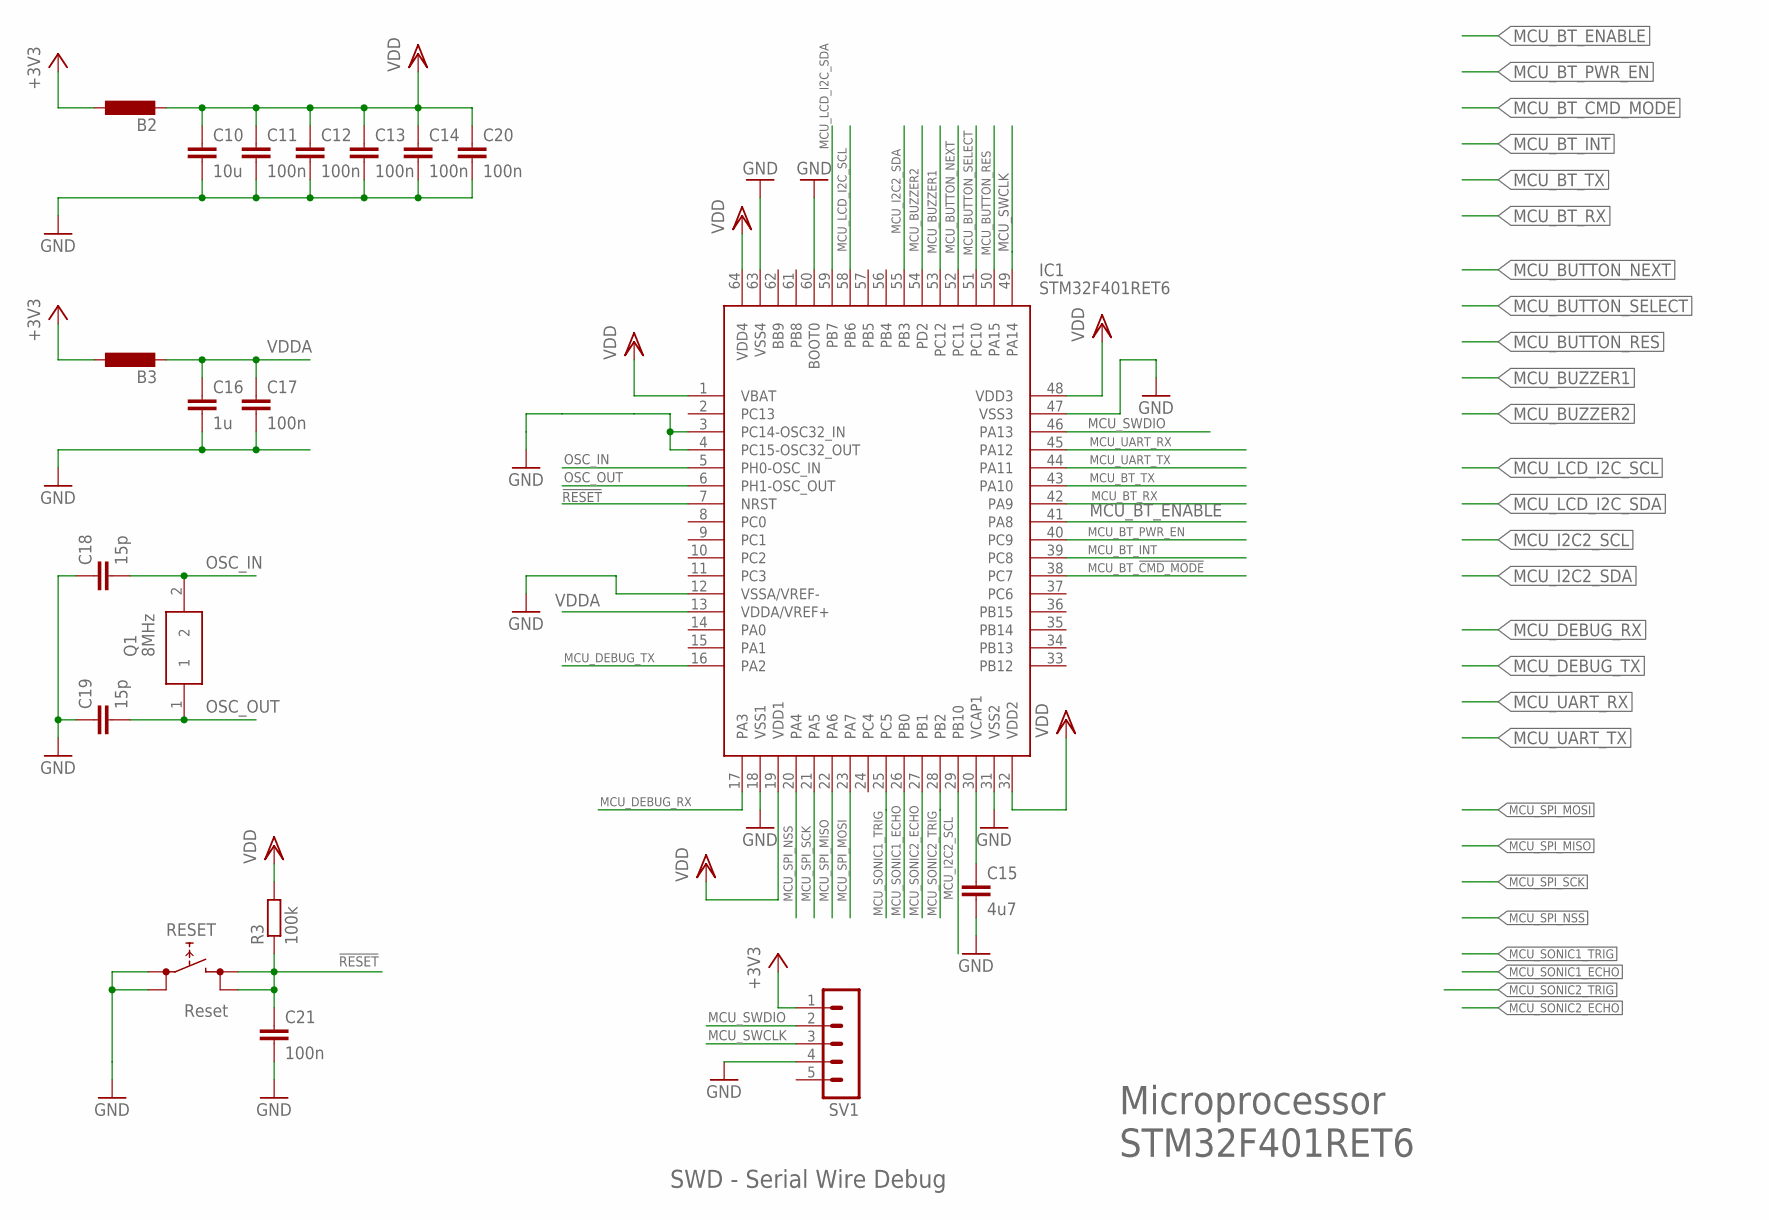
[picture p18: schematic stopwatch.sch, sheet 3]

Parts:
B2, B3: B-EU_B0805; L0805
C10: 10u; C1206
C11, C12, C13, C14, C17, C20, C21: 100n; C1206
C15: 4u7; C1206
C16: 1u; C1206
C18, C19: 15p; C1206
IC1: STM32F401RET6; QFP50P1200X1200X160-64N
Q1: 8MHz; FOXSDLF/080-20
R3: 100k; R1206
RESET: Reset; TASTER_SMD_LSG-LSH1301XX
SV1: MA05-1

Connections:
!RESET: C21.1, IC1.7 (NRST), R3.1, RESET.3, RESET.4
+3V3: B2.1, B3.1, SV1.1; also elsewhere on the board
GND: C10.2, C11.2, C12.2, C13.2, C14.2, C15.2, C16.2, C17.2, C18.1, C19.1, C20.2, C21.2, IC1.3 (PC14-OSC32_IN), IC1.4 (PC15-OSC32_OUT), IC1.12 (VSSA/VREF-), IC1.18 (VSS1), IC1.31 (VSS2), IC1.47 (VSS3), IC1.60 (BOOT0), IC1.63 (VSS4), RESET.1, RESET.2, SV1.4; also elsewhere on the board
MCU_BT_!CMD_MODE: IC1.38 (PC7); also elsewhere on the board
MCU_BT_ENABLE: IC1.41 (PA8); also elsewhere on the board
MCU_BT_INT: IC1.39 (PC8); also elsewhere on the board
MCU_BT_PWR_EN: IC1.40 (PC9); also elsewhere on the board
MCU_BT_RX: IC1.42 (PA9); also elsewhere on the board
MCU_BT_TX: IC1.43 (PA10); also elsewhere on the board
MCU_BUTTON_NEXT: IC1.52 (PC11); also elsewhere on the board
MCU_BUTTON_RES: IC1.50 (PA15); also elsewhere on the board
MCU_BUTTON_SELECT: IC1.51 (PC10); also elsewhere on the board
MCU_BUZZER1: IC1.53 (PC12); also elsewhere on the board
MCU_BUZZER2: IC1.54 (PD2); also elsewhere on the board
MCU_DEBUG_RX: IC1.17 (PA3); also elsewhere on the board
MCU_DEBUG_TX: IC1.16 (PA2); also elsewhere on the board
MCU_I2C2_SCL: IC1.29 (PB10); also elsewhere on the board
MCU_I2C2_SDA: IC1.55 (PB3); also elsewhere on the board
MCU_LCD_I2C_SCL: IC1.58 (PB6); also elsewhere on the board
MCU_LCD_I2C_SDA: IC1.59 (PB7); also elsewhere on the board
MCU_SONIC1_ECHO: IC1.26 (PB0); also elsewhere on the board
MCU_SONIC1_TRIG: IC1.25 (PC5); also elsewhere on the board
MCU_SONIC2_ECHO: IC1.27 (PB1); also elsewhere on the board
MCU_SONIC2_TRIG: IC1.28 (PB2); also elsewhere on the board
MCU_SPI_MISO: IC1.22 (PA6); also elsewhere on the board
MCU_SPI_MOSI: IC1.23 (PA7); also elsewhere on the board
MCU_SPI_NSS: IC1.20 (PA4); also elsewhere on the board
MCU_SPI_SCK: IC1.21 (PA5); also elsewhere on the board
MCU_SWCLK: IC1.49 (PA14), SV1.3
MCU_SWDIO: IC1.46 (PA13), SV1.2
MCU_UART_RX: IC1.45 (PA12); also elsewhere on the board
MCU_UART_TX: IC1.44 (PA11); also elsewhere on the board
unnamed: C15.1, IC1.30 (VCAP1)
OSC_IN: C18.2, IC1.5 (PH0-OSC_IN), Q1.2
OSC_OUT: C19.2, IC1.6 (PH1-OSC_OUT), Q1.1
VDD: B2.2, C10.1, C11.1, C12.1, C13.1, C14.1, C20.1, IC1.1 (VBAT), IC1.19 (VDD1), IC1.32 (VDD2), IC1.48 (VDD3), IC1.64 (VDD4), R3.2
VDDA: B3.2, C16.1, C17.1, IC1.13 (VDDA/VREF+)

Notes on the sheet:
SWD - Serial Wire Debug
Microprocessor STM32F401RET6

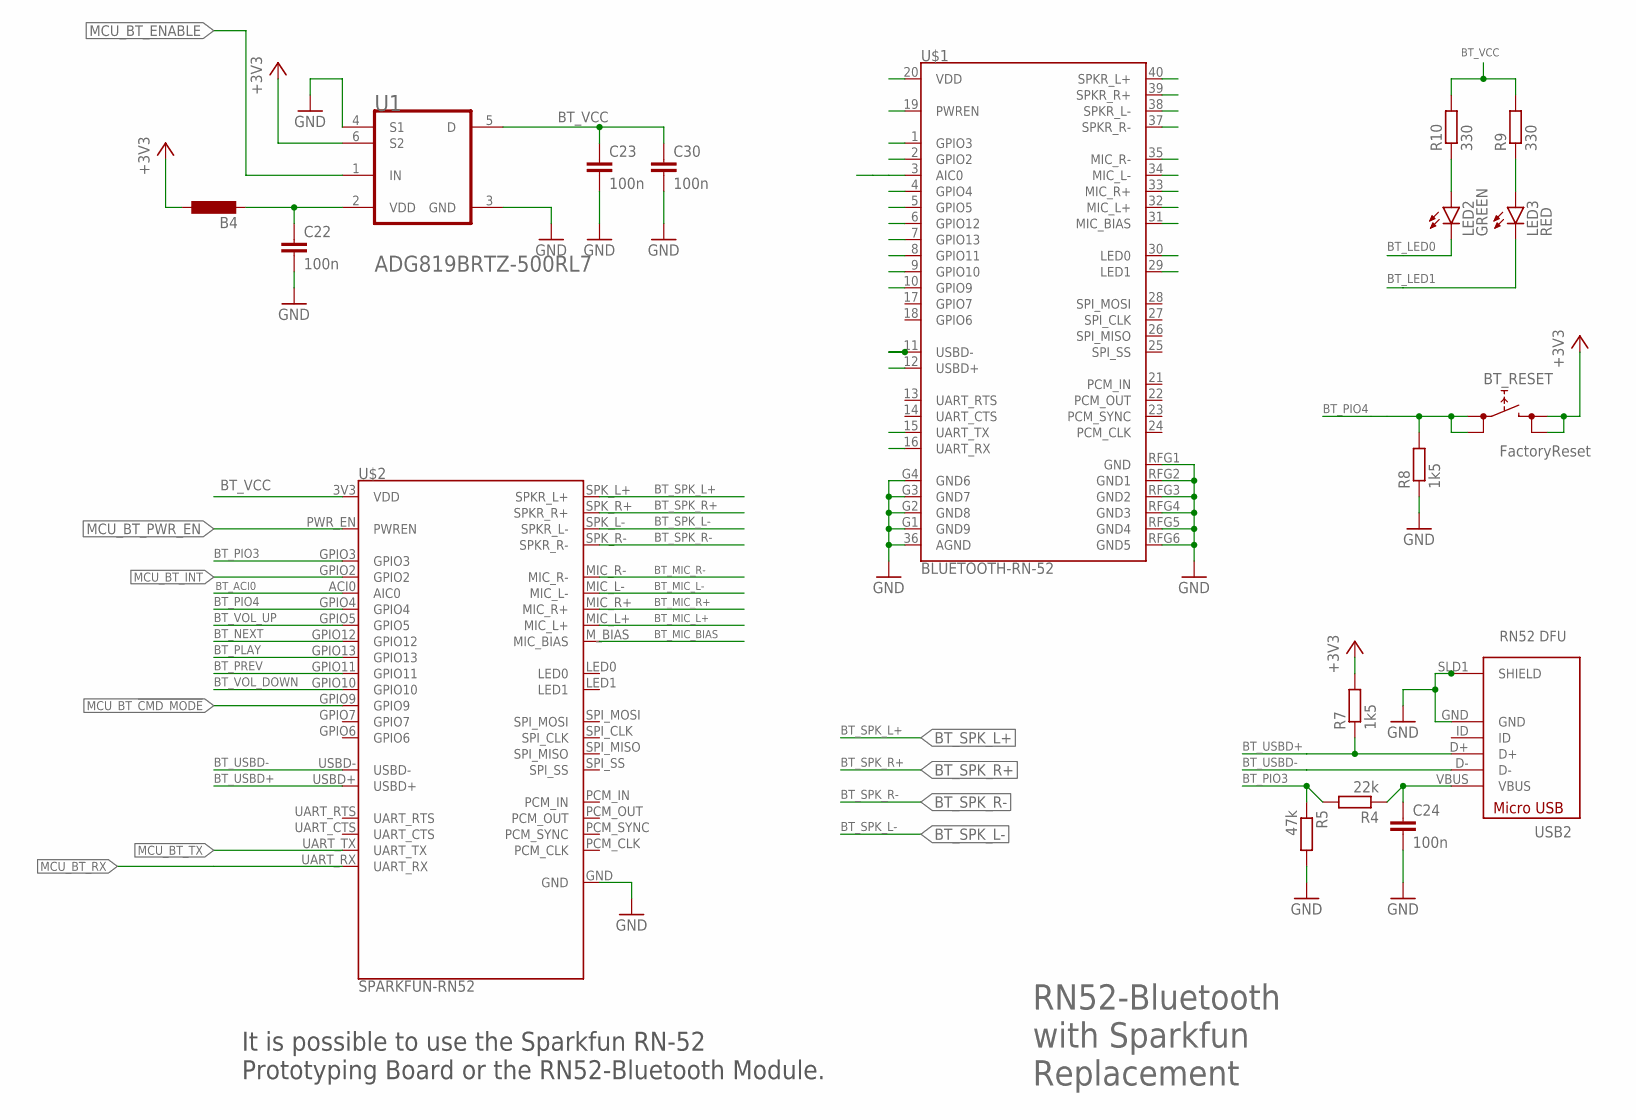
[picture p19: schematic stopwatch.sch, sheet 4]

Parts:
B4: B-EU_B0805; L0805
BT_RESET: FactoryReset; TASTER_SMD_LSG-LSH1301XX
C22, C23, C24, C30: 100n; C1206
LED2: GREEN; CHIPLED_1206
LED3: RED; CHIPLED_1206
R4: 22k; R1206
R5: 47k; R1206
R7, R8: 1k5; R1206
R9, R10: 330; R1206
U1: ANALOG_DEVICES_ADG819BRTZ-500RL7ANALOG_DEVICES_AD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; ANALOG_DEVICES_ADG819BRTZ-500RL7_1
U$1: BLUETOOTH-RN-52; RN-52
U$2: SPARKFUN-RN52
USB2: MICRO-USB; ZX62B5PA

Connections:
+3V3: B4.1, BT_RESET.3, BT_RESET.4, R7.2, U1.6 (S2); also elsewhere on the board
BT_ACI0: U$1.3 (AIC0), U$2.ACI0 (AIC0)
BT_LED0: LED2.C, U$1.30 (LED0)
BT_LED1: LED3.C, U$1.29 (LED1)
BT_MIC_BIAS: U$1.31 (MIC_BIAS), U$2.M_BIAS (MIC_BIAS)
BT_MIC_L+: U$1.32 (MIC_L+), U$2.MIC_L+
BT_MIC_L-: U$1.34 (MIC_L-), U$2.MIC_L-
BT_MIC_R+: U$1.33 (MIC_R+), U$2.MIC_R+
BT_MIC_R-: U$1.35 (MIC_R-), U$2.MIC_R-
BT_NEXT: U$1.6 (GPIO12), U$2.GPIO12
BT_PIO3: R4.2, R5.1, U$1.1 (GPIO3), U$2.GPIO3
BT_PIO4: BT_RESET.1, BT_RESET.2, R8.2, U$1.4 (GPIO4), U$2.GPIO4
BT_PLAY: U$1.7 (GPIO13), U$2.GPIO13
BT_PREV: U$1.8 (GPIO11), U$2.GPIO11
BT_SPK_L+: U$1.40 (SPKR_L+), U$2.SPK_L+ (SPKR_L+); also elsewhere on the board
BT_SPK_L-: U$1.38 (SPKR_L-), U$2.SPK_L- (SPKR_L-); also elsewhere on the board
BT_SPK_R+: U$1.39 (SPKR_R+), U$2.SPK_R+ (SPKR_R+); also elsewhere on the board
BT_SPK_R-: U$1.37 (SPKR_R-), U$2.SPK_R- (SPKR_R-); also elsewhere on the board
BT_USBD+: R7.1, U$1.12 (USBD+), U$2.USBD+, USB2.D+
BT_USBD-: U$1.11 (USBD-), U$2.USBD-, USB2.D-
BT_VCC: C23.1, C30.1, R9.2, R10.2, U1.5 (D), U$1.20 (VDD), U$2.3V3 (VDD)
BT_VOL_DOWN: U$1.9 (GPIO10), U$2.GPIO10
BT_VOL_UP: U$1.5 (GPIO5), U$2.GPIO5
GND: C22.2, C23.2, C24.2, C30.2, R5.2, R8.1, U1.3 (GND), U1.4 (S1), U$1.36 (AGND), U$1.G1 (GND9), U$1.G2 (GND8), U$1.G3 (GND7), U$1.G4 (GND6), U$1.RFG1 (GND), U$1.RFG2 (GND1), U$1.RFG3 (GND2), U$1.RFG4 (GND3), U$1.RFG5 (GND4), U$1.RFG6 (GND5), U$2.GND, USB2.GND, USB2.SLD1 (SHIELD), USB2.SLD2 (SHIELD2), USB2.SLD3 (SHIELD3), USB2.SLD4 (SHIELD4), USB2.SLD5 (SHIELD5), USB2.SLD6 (SHIELD6); also elsewhere on the board
MCU_BT_!CMD_MODE: U$1.10 (GPIO9), U$2.GPIO9; also elsewhere on the board
MCU_BT_ENABLE: U1.1 (IN); also elsewhere on the board
MCU_BT_INT: U$1.2 (GPIO2), U$2.GPIO2; also elsewhere on the board
MCU_BT_PWR_EN: U$1.19 (PWREN), U$2.PWR_EN (PWREN); also elsewhere on the board
MCU_BT_RX: U$1.16 (UART_RX), U$2.UART_RX; also elsewhere on the board
MCU_BT_TX: U$1.15 (UART_TX), U$2.UART_TX; also elsewhere on the board
unnamed: B4.2, C22.1, U1.2 (VDD)
unnamed: C24.1, R4.1, USB2.VBUS
unnamed: LED2.A, R10.1
unnamed: LED3.A, R9.1

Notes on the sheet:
RN52 DFU
RN52-Bluetooth with Sparkfun Replacement
It is possible to use the Sparkfun RN-52 Prototyping Board or the RN52-Bluetooth Module.

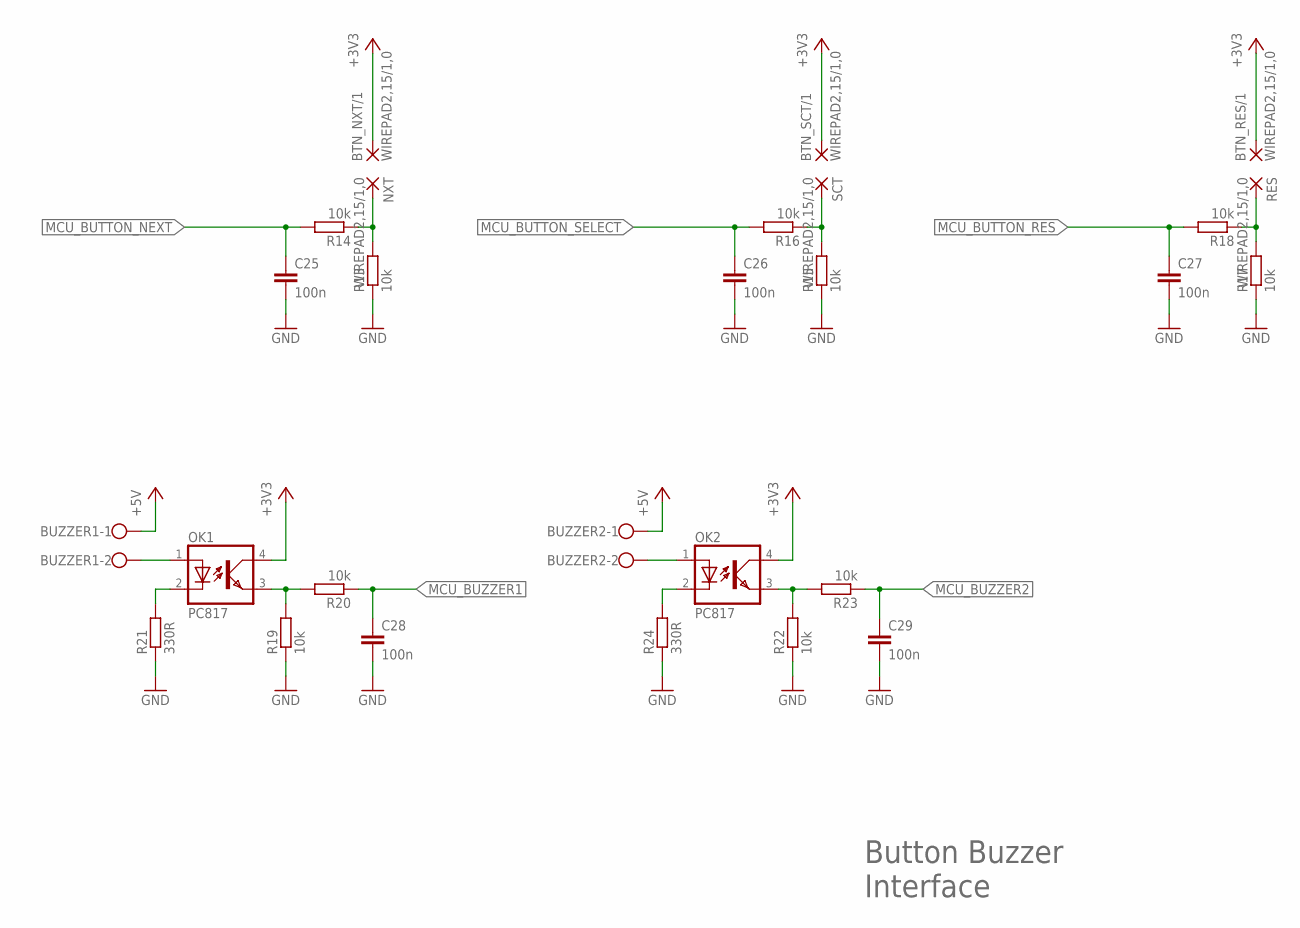
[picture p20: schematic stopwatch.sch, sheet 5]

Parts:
BTN_NXT/1: WIREPAD2,15/1,0; 2,15/1,0
BTN_RES/1: WIREPAD2,15/1,0; 2,15/1,0
BTN_SCT/1: WIREPAD2,15/1,0; 2,15/1,0
BUZZER1, BUZZER2: W237-102
C25, C26, C27, C28, C29: 100n; C1206
NXT: WIREPAD2,15/1,0; 2,15/1,0
OK1, OK2: PC817; DIL04
R13, R14, R15, R16, R17, R18, R19, R20, R22, R23: 10k; R1206
R21, R24: 330R; R1206
RES: WIREPAD2,15/1,0; 2,15/1,0
SCT: WIREPAD2,15/1,0; 2,15/1,0

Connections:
+3V3: BTN_NXT/1.1, BTN_RES/1.1, BTN_SCT/1.1, OK1.4 (COL), OK2.4 (COL); also elsewhere on the board
+5V: BUZZER1.1, BUZZER2.1; also elsewhere on the board
GND: C25.2, C26.2, C27.2, C28.2, C29.2, R13.1, R15.1, R17.1, R19.1, R21.1, R22.1, R24.1; also elsewhere on the board
MCU_BUTTON_NEXT: C25.1, R14.2; also elsewhere on the board
MCU_BUTTON_RES: C27.1, R18.2; also elsewhere on the board
MCU_BUTTON_SELECT: C26.1, R16.2; also elsewhere on the board
MCU_BUZZER1: C28.1, R20.1; also elsewhere on the board
MCU_BUZZER2: C29.1, R23.1; also elsewhere on the board
unnamed: NXT.1, R13.2, R14.1
unnamed: R15.2, R16.1, SCT.1
unnamed: R17.2, R18.1, RES.1
unnamed: BUZZER1.2, OK1.1 (A)
unnamed: OK1.2 (C), R21.2
unnamed: OK1.3 (EMIT), R19.2, R20.2
unnamed: BUZZER2.2, OK2.1 (A)
unnamed: OK2.2 (C), R24.2
unnamed: OK2.3 (EMIT), R22.2, R23.2

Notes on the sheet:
Button Buzzer Interface

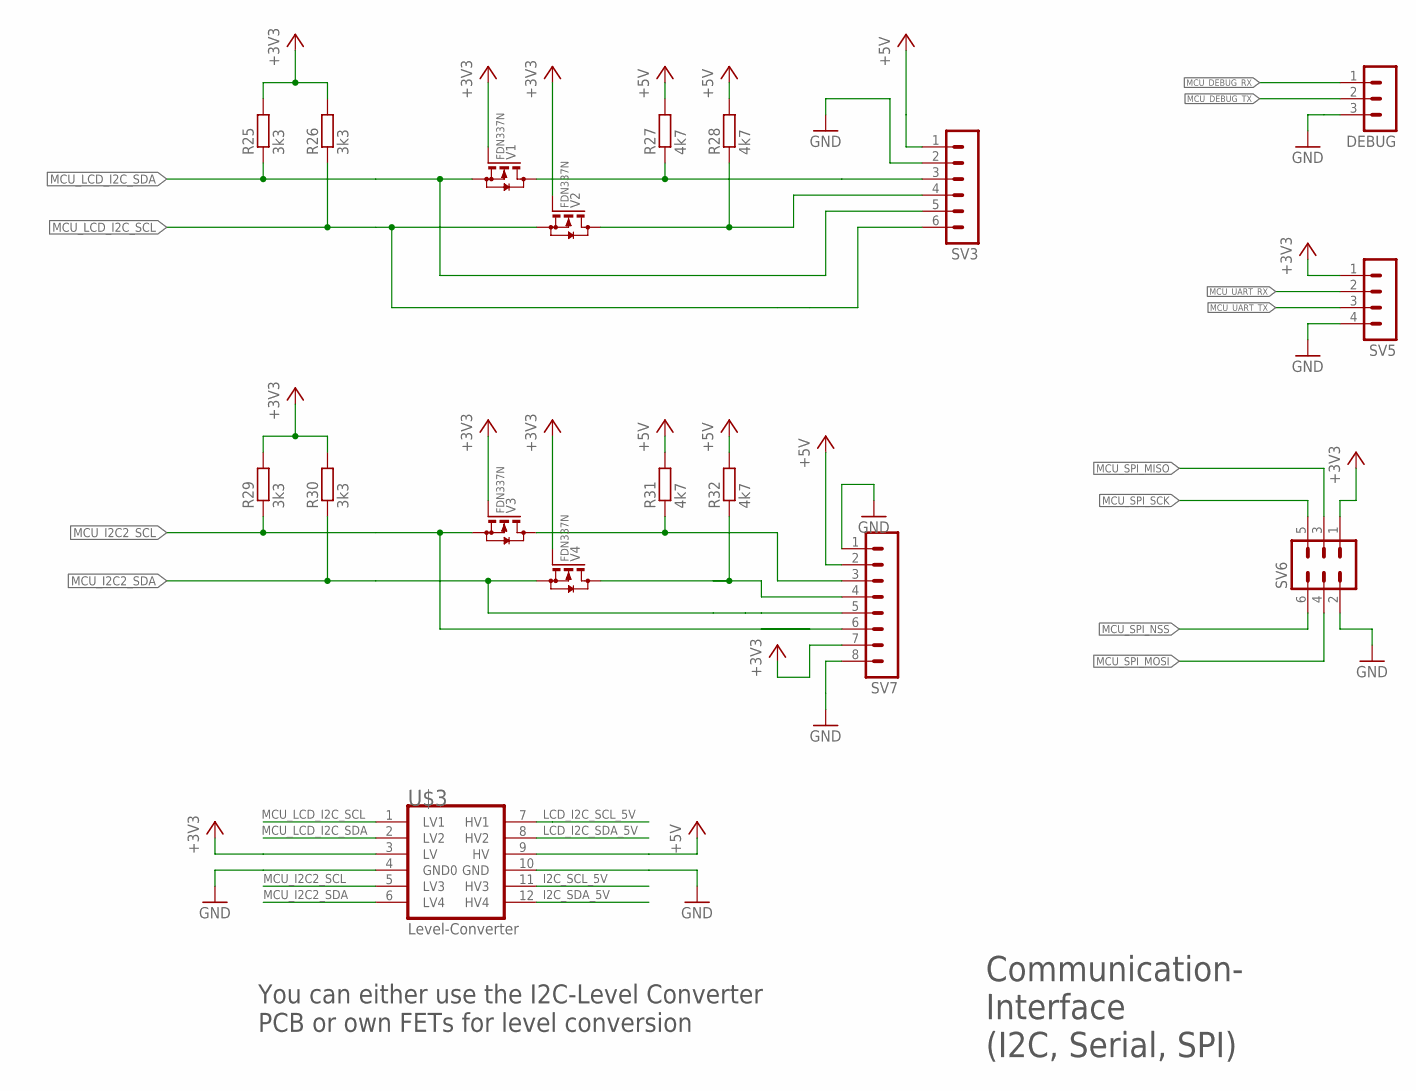
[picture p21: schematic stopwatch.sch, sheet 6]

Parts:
DEBUG: MA03-1
R25, R26, R29, R30: 3k3; R1206
R27, R28, R31, R32: 4k7; R1206
SV3: MA06-1
SV5: MA04-1
SV6: MA03-2
SV7: MA08-1
U$3: I2C-LEVELCONVERTER-PCB
V1, V2, V3, V4: FDN337N; SOT23

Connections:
+3V3: R25.2, R26.2, R29.2, R30.2, SV5.1, SV6.1, SV7.7, U$3.3 (LV), V1.1 (G), V2.1 (G), V3.1 (G), V4.1 (G); also elsewhere on the board
+5V: R27.2, R28.2, R31.2, R32.2, SV3.1, SV7.2, U$3.9 (HV); also elsewhere on the board
GND: DEBUG.3, SV3.2, SV5.4, SV6.2, SV7.1, SV7.8, U$3.4 (GND0), U$3.10 (GND); also elsewhere on the board
I2C_SCL_5V: R31.1, SV7.3, U$3.11 (HV3), V3.3 (D)
I2C_SDA_5V: R32.1, SV7.4, U$3.12 (HV4), V4.3 (D)
LCD_I2C_SCL_5V: R28.1, SV3.4, U$3.7 (HV1), V2.3 (D)
LCD_I2C_SDA_5V: R27.1, SV3.3, U$3.8 (HV2), V1.3 (D)
MCU_DEBUG_RX: DEBUG.1; also elsewhere on the board
MCU_DEBUG_TX: DEBUG.2; also elsewhere on the board
MCU_I2C2_SCL: R29.1, SV7.6, U$3.5 (LV3), V3.2 (S); also elsewhere on the board
MCU_I2C2_SDA: R30.1, SV7.5, U$3.6 (LV4), V4.2 (S); also elsewhere on the board
MCU_LCD_I2C_SCL: R26.1, SV3.6, U$3.1 (LV1), V2.2 (S); also elsewhere on the board
MCU_LCD_I2C_SDA: R25.1, SV3.5, U$3.2 (LV2), V1.2 (S); also elsewhere on the board
MCU_SPI_MISO: SV6.3; also elsewhere on the board
MCU_SPI_MOSI: SV6.4; also elsewhere on the board
MCU_SPI_NSS: SV6.6; also elsewhere on the board
MCU_SPI_SCK: SV6.5; also elsewhere on the board
MCU_UART_RX: SV5.2; also elsewhere on the board
MCU_UART_TX: SV5.3; also elsewhere on the board

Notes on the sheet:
Communication- Interface (I2C, Serial, SPI)
You can either use the I2C-Level Converter PCB or own FETs for level conversion

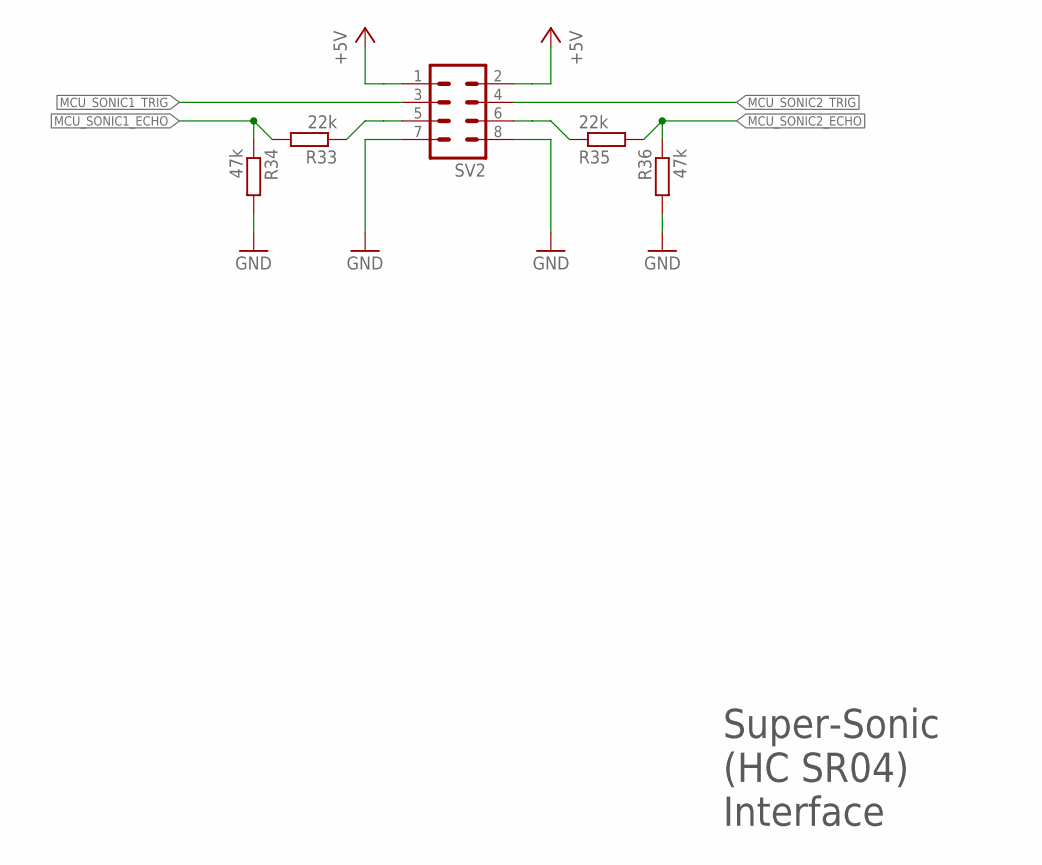
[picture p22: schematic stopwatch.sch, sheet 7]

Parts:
R33, R35: 22k; R1206
R34, R36: 47k; R1206
SV2: MA04-2

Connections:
+5V: SV2.1, SV2.2; also elsewhere on the board
GND: R34.2, R36.2, SV2.7, SV2.8; also elsewhere on the board
MCU_SONIC1_ECHO: R33.2, R34.1; also elsewhere on the board
MCU_SONIC1_TRIG: SV2.3; also elsewhere on the board
MCU_SONIC2_ECHO: R35.2, R36.1; also elsewhere on the board
MCU_SONIC2_TRIG: SV2.4; also elsewhere on the board
unnamed: R35.1, SV2.6
unnamed: R33.1, SV2.5

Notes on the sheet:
Super-Sonic (HC SR04) Interface

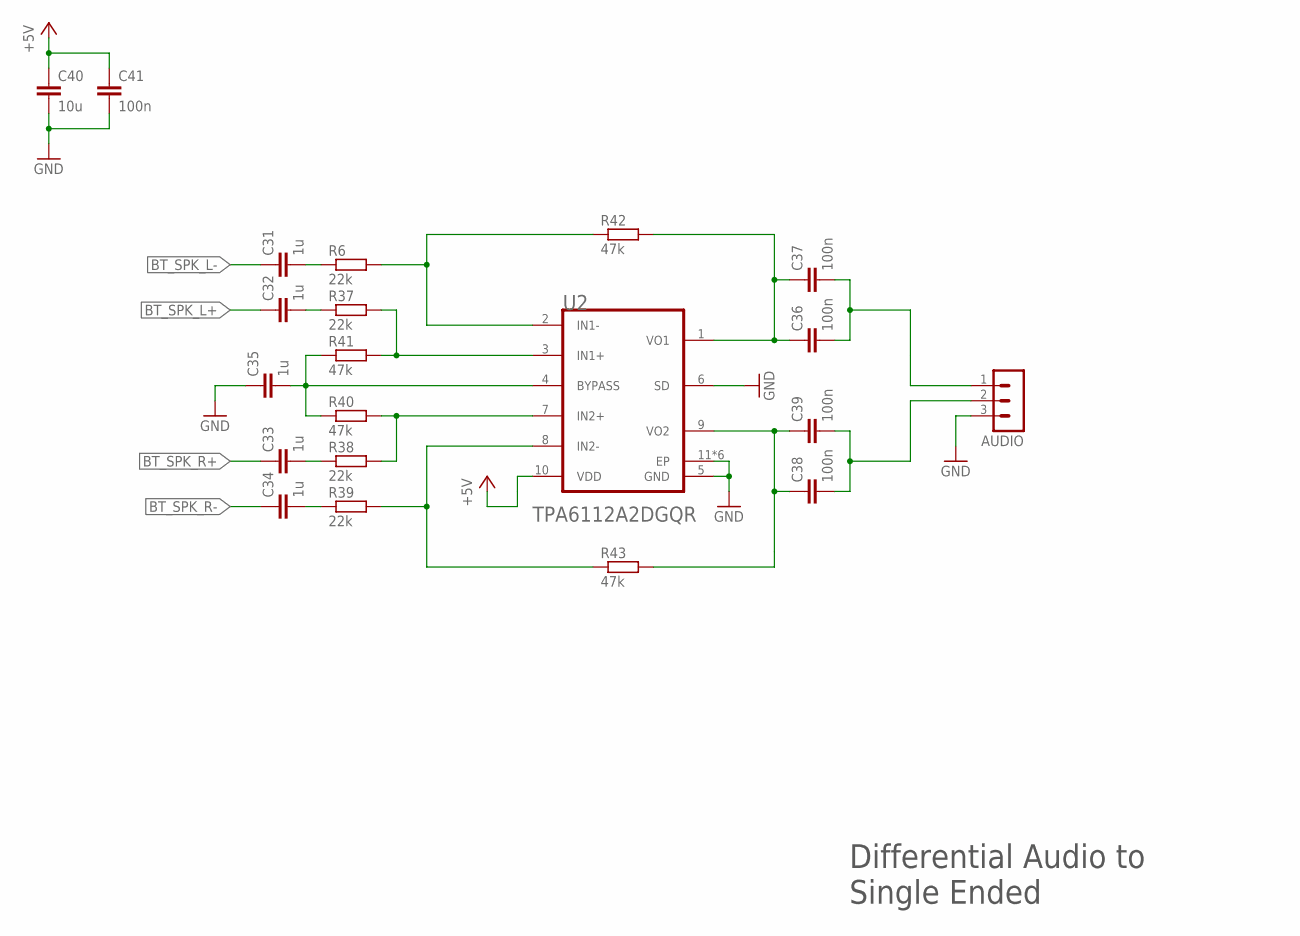
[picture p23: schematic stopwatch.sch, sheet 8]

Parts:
AUDIO: MA03-1
C31, C32, C33, C34, C35: 1u; C1206
C36, C37, C38, C39, C41: 100n; C1206
C40: 10u; C1206
R6, R37, R38, R39: 22k; R1206
R40, R41, R42, R43: 47k; R1206
U2: TEXAS_INSTRUMENTS_TPA6112A2DGQRTEXAS_INSTRUMENTS_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; TEXAS_INSTRUMENTS_TPA6112A2DGQR_1

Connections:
+5V: C40.1, C41.1, U2.10 (VDD); also elsewhere on the board
BT_SPK_L+: C32.1; also elsewhere on the board
BT_SPK_L-: C31.1; also elsewhere on the board
BT_SPK_R+: C33.1; also elsewhere on the board
BT_SPK_R-: C34.1; also elsewhere on the board
GND: AUDIO.3, C35.1, C40.2, C41.2, U2.5 (GND), U2.6 (SD), U2.11 (EP), U2.PAD_1 (EP), U2.PAD_2 (EP), U2.PAD_3 (EP), U2.PAD_4 (EP), U2.PAD_5 (EP); also elsewhere on the board
unnamed: R6.2, R42.1, U2.2 (IN1-)
unnamed: R39.2, R43.1, U2.8 (IN2-)
unnamed: AUDIO.2, C38.2, C39.2
unnamed: C38.1, C39.1, R43.2, U2.9 (VO2)
unnamed: C36.1, C37.1, R42.2, U2.1 (VO1)
unnamed: C31.2, R6.1
unnamed: C32.2, R37.1
unnamed: C33.2, R38.1
unnamed: C34.2, R39.1
unnamed: R37.2, R41.2, U2.3 (IN1+)
unnamed: R38.2, R40.2, U2.7 (IN2+)
unnamed: C35.2, R40.1, R41.1, U2.4 (BYPASS)
unnamed: AUDIO.1, C36.2, C37.2

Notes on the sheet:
Differential Audio to Single Ended

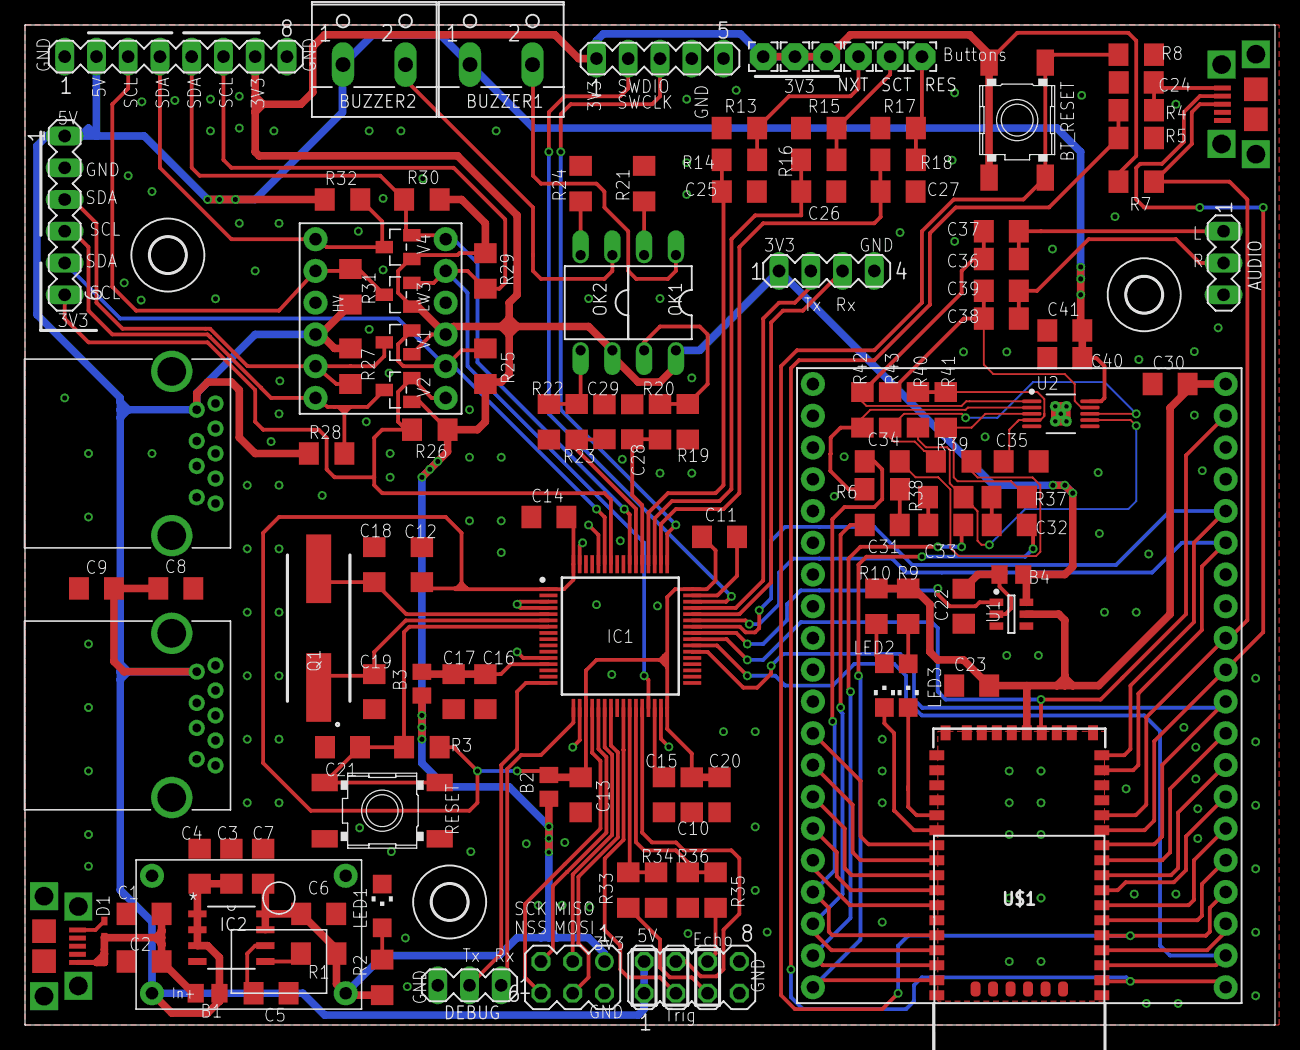
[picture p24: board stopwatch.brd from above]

Board: 2 copper layers, 100.0 x 80.0 mm, 130 parts (0 on the bottom side), 96 nets.

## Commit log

2020-03-22 inital commit
    [BOM.csv, BOM2.csv, stopwatch.brd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]
2020-04-12 initial commit 3d-case
    [Assembled.FCStd, Case2.FCStd, Cover.FCStd]
2020-04-12 fixed display position holes
    [Cover.FCStd]
2020-04-12 added button mount
    [Cover.FCStd]
2020-04-12 height fix
    [Cover.FCStd]
2020-04-12 display mnt holes changes
    [Cover.FCStd]
